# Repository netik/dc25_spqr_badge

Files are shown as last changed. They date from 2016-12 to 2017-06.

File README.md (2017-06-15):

# DEF CON 25 - The Ides of DEF CON PCB

In this folder you will find the KiCad board, schematic, and 
fabrication outputs for our Unofficial DEFCON 25 badge. The board layout was designed with [KiCad](http://kicad-pcb.org/), an open source schematic capture and PCB layout program. You will probably want the latest beta code as we had many issues working with this design and the release software.

We used **KiCad version 2016-12-18 revision 3ffa37c-master** for this design.

"fabrication-final" contains our final output gerbers which, along with the xyrs BOM file can be sent to MacroFab for construction for around $180. The cost goes down as you manufacture more boards, obviously. 

[Download the firmware source](https://github.com/netik/chibios-orchard) and flash it to this board using a SWD style debugger. 

---

Aside from the PCB and BOM that is here, you will also need:

**(qty 1) Micro SD Card, at least 4GB**

* We recommend class 4 cards because we support video playback and need some performance. 
* Copy the entire contents of the [latest SD card](https://dc25spqr.com), to the root directory of the SD Card. Name the SD card "SPQR_DC25" to be compatible with the existing update scripts if you'd like.

**(qty 1) ER-TFTM-028-4 (v4.0) 320x240 TFT Touch Screen**

* Go to Buydisplay.com: http://www.buydisplay.com/default/2-8-inch-tft-touch-shield-for-arduino-w-capacitive-touch-screen-module
* Under "Interface" select Pin Header Connection 4-Wire SPI + US$0.33
* Under "Power Supply (Typ.)" select VDD=3.3V
* Under "Touch Panel (Attached by default)" select: "2.8" Resistive Touch Panel with Controller
* Leave "Font Chip" selection empty.

**(qty 1) PKCELL 3.7v 1200mAh 3.7v LiPo with JST connector**

* Go to Adafruit, buy this: https://www.adafruit.com/product/258 ($10 or so)
* If you are creating these in bulk, go directly to PKCELL and buy them from Shenzen. They are $1.25 or so from China.
* If you use another battery, be sure and verify polarity of the JST connector!

**(qty 2 or qty 4 if you are paranoid) Standoffs and screws to hold up the screen**

* Wurth 970110151 with M2.5 x 0.45 screws
* This is Mouser part 855-R25-1001102 R25-1001102 for the M2.5 x 11mm HEX Standoff
* Screws can be had from Digkey as part 36-29300-ND MACHINE SCREW PAN SLOTTED M2.5
* The spacing is tricky and we had to work to get the screen to sit squarely on the board, substituting other standoffs will probably not work here.

**Misc**

* A small piece of double-sided tape to hold the battery to the back of the PCB. We used velcro dots, but double sided tape feels better and holds the battery closer to the board.
* A Lanyard -- we Like the "Lobster claw" type, a double-ended lanyard with two clips so you can wear the badge up and down or left-right depending on how you'd like.

--

@netik

05/04/2017

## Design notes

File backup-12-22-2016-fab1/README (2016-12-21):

These are the KiCad board, schematic, and fabrication outputs for our
Unofficial DEFCON 25 badge.

Stuff in the fabrication folder was set to MacroFab for prototype v1
on 12/20/2016. At today's prices, a board costs about $216 to make, or
$500 for two.

The firmware is available in my checkout of the chibios-orchard repo.

It's not even remotely near done yet, but I'm storing it here to keep
track of things.

--
@netik
12/20/2016

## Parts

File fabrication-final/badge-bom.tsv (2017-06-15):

# Generated by MacroFab for PCB 4dj0a6, version 10.
# DESIGNATOR | X_LOC | Y_LOC | ROTATION | SIDE | TYPE | X_SIZE | Y_SIZE | VALUE | FOOTPRINT | POPULATE | MPN | MPN1 | MPN2 | MPN3
 | 2381.84 | 2081.92 | 180 | 2 | 2 | 0 | 0 | logos:phobos_19mm_x_5.5mm 0 " 2381.84 2081.92 180 2 2 0 0 | logos:hw_200dpi | 0
 | 2381.84 | 2081.92 | 180 | 2 | 2 | 0 | 0 | logos:grimm_600dpi 0 " 2381.84 2081.92 180 2 2 0 0 | logos:redteam_31_40 | 0
 | 2381.84 | 2081.92 | 180 | 2 | 2 | 0 | 0 | logos:laurel_right 0 " 2381.84 2081.92 180 2 2 0 0 | logos:laurel | 0
A1 | 663.338 | 2281.92 | 180 | 1 | 1 | 421.26 | 188.976 | 7488910092_ANTENNA | jna-parts:Antenna_Wurth_7488910092 | 1 | 7488910092 |  |  |  | 7488910092
BT1 | 1764.72 | 2289.79 | 270 | 2 | 1 | 330.709 | 354.331 | Battery 3.7v 1000mAh | Connectors_JST:JST_PH_S2B-PH-SM4-TB_02x2.00mm_Angled | 1 | 1769 |  |  |  | 1769
C1 | 1844.44 | 2856.72 | 90 | 1 | 1 | 157.48 | 49.2126 | 0.1uF | Capacitors_SMD:C_0805_HandSoldering | 1
C10 | 2612.16 | 189.4 | 90 | 1 | 1 | 157.48 | 49.2126 | 0.1uF | Capacitors_SMD:C_0805_HandSoldering | 1
C11 | 2214.52 | 187.431 | 90 | 1 | 1 | 157.48 | 49.2126 | 0.1uF | Capacitors_SMD:C_0805_HandSoldering | 1
C12 | 1844.44 | 199.242 | 90 | 1 | 1 | 157.48 | 49.2126 | 0.1uF | Capacitors_SMD:C_0805_HandSoldering | 1
C13 | 1952.71 | 1262.23 | 0 | 1 | 1 | 157.48 | 49.2126 | 1uF | Capacitors_SMD:C_0805_HandSoldering | 1
C14 | 1677.12 | 1842.94 | 180 | 1 | 1 | 157.48 | 62.9921 | 10uF | Capacitors_SMD:C_1206 | 1
C15 | 1686.96 | 1409.87 | 0 | 1 | 1 | 157.48 | 62.9921 | 10uF | Capacitors_SMD:C_1206 | 1
C16 | 3320.82 | 2335.07 | 0 | 1 | 1 | 157.48 | 49.2126 | 220pF | Capacitors_SMD:C_0805_HandSoldering | 1 | C0805C221K5GACTU |  |  |  | C0805C221K5GACTU
C17 | 2848.38 | 2029.95 | 90 | 1 | 1 | 157.48 | 49.2126 | 11pF | Capacitors_SMD:C_0805_HandSoldering | 1 | C0805C110J5GACTU |  |  |  | C0805C110J5GACTU
C18 | 3324.75 | 2451.21 | 0 | 1 | 1 | 122.047 | 29.5276 | 0.01uF | Capacitors_SMD_C_0603_HandSoldering | 1 | MF-CAP-0603-0.01uF |  |  |  | MF-CAP-0603-0.01uF
C19 | 2730.27 | 2285.86 | 270 | 1 | 1 | 122.047 | 29.5276 | 2pF | Capacitors_SMD:C_0603_HandSoldering | 1 | C1608C0G1H020C080AA |  |  |  | C1608C0G1H020C080AA
C2 | 2218.46 | 2856.72 | 90 | 1 | 1 | 157.48 | 49.2126 | 0.1uF | Capacitors_SMD:C_0805_HandSoldering | 1
C20 | 3675.15 | 2335.07 | 0 | 1 | 1 | 157.48 | 49.2126 | 0.1uF | Capacitors_SMD:C_0805_HandSoldering | 1
C21 | 3675.15 | 2453.18 | 0 | 1 | 1 | 157.48 | 49.2126 | 0.1uF | Capacitors_SMD:C_0805_HandSoldering | 1
C22 | 2218.46 | 2128.38 | 0 | 1 | 1 | 157.48 | 49.2126 | 0.1uF | Capacitors_SMD:C_0805_HandSoldering | 1
C23 | 2592.47 | 2443.34 | 0 | 1 | 1 | 122.047 | 29.5276 | 6.8pF | Capacitors_SMD_C_0603_HandSoldering | 1 | 06035A6R8CAT2A |  |  |  | 06035A6R8CAT2A
C24 | 2415.31 | 2285.86 | 270 | 1 | 1 | 122.047 | 29.5276 | 7.5pF | 0603 | 1 | 251R14S7R5CV4T |  |  |  | 251R14S7R5CV4T
C25 | 2074.36 | 2381.92 | 270 | 1 | 1 | 157.48 | 49.2126 | 5.6pF | Capacitors_SMD:C_0805_HandSoldering | 1 | CL21C5R6CBANNNC |  |  |  | CL21C5R6CBANNNC
C26 | 1883.81 | 2423.65 | 0 | 1 | 1 | 157.48 | 49.2126 | 100pF | Capacitors_SMD:C_0805_HandSoldering | 1 | 08055A101KAT2A |  |  |  | 08055A101KAT2A
C27 | 997.983 | 1990.58 | 270 | 1 | 1 | 157.48 | 49.2126 | 1.2pF | Capacitors_SMD:C_0805_HandSoldering | 1 | CL21C1R2BBANNNC |  |  |  | CL21C1R2BBANNNC
C28 | 466.487 | 2010.27 | 270 | 1 | 1 | 157.48 | 49.2126 | 3.3pF | Capacitors_SMD:C_0805_HandSoldering | 1 | 08055A3R3CAT2A |  |  |  | 08055A3R3CAT2A
C29 | 5171.21 | 2502.39 | 180 | 1 | 1 | 157.48 | 49.2126 | 1uF | Capacitors_SMD:C_0805_HandSoldering | 1
C3 | 2612.16 | 2856.72 | 90 | 1 | 1 | 157.48 | 49.2126 | 0.1uF | Capacitors_SMD:C_0805_HandSoldering | 1
C30 | 4029.48 | 1144.12 | 0 | 1 | 1 | 157.48 | 49.2126 | 0.1uF | Capacitors_SMD:C_0805_HandSoldering | 1
C31 | 3694.83 | 1400.03 | 0 | 1 | 1 | 157.48 | 49.2126 | 10uF | Capacitors_SMD:C_0805_HandSoldering | 1 | CL21A106KQCLRNC |  |  |  | CL21A106KQCLRNC
C32 | 4226.33 | 750.423 | 90 | 1 | 1 | 157.48 | 49.2126 | 0.1uF | Capacitors_SMD:C_0805_HandSoldering | 1
C33 | 3242.08 | 2029.95 | 90 | 1 | 1 | 157.48 | 49.2126 | 11pF | Capacitors_SMD:C_0805_HandSoldering | 1 | C0805C110J5GACTU |  |  |  | C0805C110J5GACTU
C34 | 2641.29 | 1671.29 | 90 | 1 | 1 | 157.48 | 49.2126 | 0.1uF | Capacitors_SMD:C_0805_HandSoldering | 1
C35 | 3372.98 | 1666.76 | 270 | 1 | 1 | 157.48 | 49.2126 | 0.1uF | Capacitors_SMD:C_0805_HandSoldering | 1
C36 | 2777.9 | 1833.1 | 180 | 1 | 1 | 157.48 | 49.2126 | 0.1uF | Capacitors_SMD:C_0805_HandSoldering | 1
C4 | 3005.86 | 2856.72 | 90 | 1 | 1 | 157.48 | 49.2126 | 0.1uF | Capacitors_SMD:C_0805_HandSoldering | 1
C42 | 3562.55 | 1975.23 | 270 | 1 | 1 | 157.48 | 49.2126 | 10uF | Capacitors_SMD:C_0805_HandSoldering | 1 | CL21A106KQCLRNC |  |  |  | CL21A106KQCLRNC
C43 | 3682.63 | 1971.68 | 270 | 1 | 1 | 157.48 | 49.2126 | Capacitors_SMD:C_0805_HandSoldering | 1 | 1 | CL21A106KQCLRNC |  |  | CL21A106KQCLRNC | CL21A106KQCLRNC
C44 | 4025.54 | 2455.15 | 0 | 1 | 1 | 122.047 | 29.5276 | 0.01uF | Capacitors_SMD_C_0603_HandSoldering | 1 | MF-CAP-0603-0.01uF |  |  |  | MF-CAP-0603-0.01uF
C45 | 4014.52 | 2135.86 | 270 | 1 | 1 | 98.4 | 200.5 | 10uF | MF_Passives:MF_Passives-CP4MM | 1 | MF-CAP-4MM-10uF |  |  |  | MF-CAP-4MM-10uF
C46 | 4675.15 | 2608.69 | 180 | 1 | 1 | 98.4 | 200.5 | 10uF | MF_Passives:MF_Passives-CP4MM | 1 | MF-CAP-4MM-10uF |  |  |  | MF-CAP-4MM-10uF
C47 | 3844.05 | 1657.9 | 270 | 1 | 1 | 157.48 | 49.2126 | .047uF | Capacitors_SMD:C_0805_HandSoldering | 1 | 08053C473JAT2A |  |  |  | 08053C473JAT2A
C48 | 4014.52 | 1721.68 | 180 | 1 | 1 | 157.48 | 49.2126 | 10uF | Capacitors_SMD:C_0805_HandSoldering | 1 | CL21A106KQCLRNC |  |  |  | CL21A106KQCLRNC
C49 | 4899.56 | 1880.34 | 180 | 1 | 1 | 125.9 | 275.3 | 100uF | MF_Passives:MF_Passives-CP6.3MM | 1 | MF-CAP-6.3MM-100uF |  |  |  | MF-CAP-6.3MM-100uF
C5 | 3399.56 | 2856.72 | 90 | 1 | 1 | 157.48 | 49.2126 | 0.1uF | Capacitors_SMD:C_0805_HandSoldering | 1
C6 | 3793.26 | 2856.72 | 90 | 1 | 1 | 157.48 | 49.2126 | 0.1uF | Capacitors_SMD:C_0805_HandSoldering | 1
C7 | 3793.26 | 199.242 | 90 | 1 | 1 | 157.48 | 49.2126 | 0.1uF | Capacitors_SMD:C_0805_HandSoldering | 1
C8 | 3399.56 | 199.242 | 90 | 1 | 1 | 157.48 | 49.2126 | 0.1uF | Capacitors_SMD:C_0805_HandSoldering | 1
C9 | 3005.86 | 199.242 | 90 | 1 | 1 | 157.48 | 49.2126 | 0.1uF | Capacitors_SMD:C_0805_HandSoldering | 1
D1 | 4521.61 | 2423.65 | 0 | 1 | 1 | 129.8 | 47.2 | RED PWROK | LEDs:LED_0805 | 1 | MF-LED-0805-RED |  |  |  | MF-LED-0805-RED
D2 | 4521.61 | 2226.8 | 0 | 1 | 1 | 129.8 | 47.2 | GREEN SDIO | LEDs:LED_0805 | 1 | MF-LED-0805-GREEN |  |  |  | MF-LED-0805-GREEN
D3 | 4521.61 | 2029.95 | 0 | 1 | 1 | 129.8 | 47.2 | RED UTX | LEDs:LED_0805 | 1 | MF-LED-0805-RED |  |  |  | MF-LED-0805-RED
D4 | 4521.61 | 1833.1 | 0 | 1 | 1 | 129.8 | 47.2 | GREEN URX | LEDs:LED_0805 | 1 | MF-LED-0805-GREEN |  |  |  | MF-LED-0805-GREEN
D5 | 4521.61 | 1636.25 | 0 | 1 | 1 | 129.8 | 47.2 | RED (CHARGING) | LEDs:LED_0805 | 1 | MF-LED-0805-RED |  |  |  | MF-LED-0805-RED
D6 | 4521.61 | 1439.4 | 0 | 1 | 1 | 129.8 | 47.2 | GRN (DONE) | LEDs:LED_0805 | 1 | MF-LED-0805-GREEN |  |  |  | MF-LED-0805-GREEN
D7 | 4521.61 | 1242.55 | 0 | 1 | 1 | 129.8 | 47.2 | RED RFTX | LEDs:LED_0805 | 1 | MF-LED-0805-RED |  |  |  | MF-LED-0805-RED
D8 | 4521.61 | 1045.7 | 0 | 1 | 1 | 129.8 | 47.2 | GRN RFRX | LEDs:LED_0805 | 1 | MF-LED-0805-GREEN |  |  |  | MF-LED-0805-GREEN
H1 | 1679.09 | 2659.87 | 0 | 1 | 2 | 125.984 | 125.984 | CONN_01X01 | Mounting_Holes_MountingHole_3_2mm_M3_DIN965 | 0
H2 | 4297.2 | 2663.81 | 0 | 1 | 2 | 125.984 | 125.984 | CONN_01X01 | Mounting_Holes_MountingHole_3_2mm_M3_DIN965 | 0
H3 | 1679.09 | 459.085 | 0 | 1 | 2 | 125.984 | 125.984 | CONN_01X01 | Mounting_Holes_MountingHole_3_2mm_M3_DIN965 | 0
H4 | 4297.2 | 459.085 | 0 | 1 | 2 | 125.984 | 125.984 | CONN_01X01 | Mounting_Holes_MountingHole_3_2mm_M3_DIN965 | 0
H5 | 1253.89 | 2856.72 | 0 | 1 | 2 | 125.984 | 125.984 | CONN_01X01 | Mounting_Holes_MountingHole_3_2mm_M3_DIN965 | 0
H6 | 4757.83 | 2856.72 | 0 | 1 | 2 | 125.984 | 125.984 | CONN_01X01 | Mounting_Holes_MountingHole_3_2mm_M3_DIN965 | 0
H7 | 144.046 | 1504.2 | 0 | 1 | 2 | 125.984 | 125.984 | CONN_01X01 | Mounting_Holes_MountingHole_3_2mm_M3_DIN965 | 0
J2 | 2560.58 | 671.093 | 90 | 1 | 2 | 91.3386 | 241.339 | JTAG | Pin_Headers:Pin_Header_Straight_2x05_Pitch1.27mm | 1 | M50-3500542 |  |  |  | M50-3500542
L1 | 2897.59 | 2433.49 | 90 | 1 | 1 | 78.8 | 47.2 | 4.7nH | Inductors_NEOSID:Neosid_Inductor_SM0603CG | 1 | LQG18HN4N7S00D |  |  |  | LQG18HN4N7S00D
L2 | 3074.75 | 2433.49 | 90 | 1 | 1 | 78.8 | 47.2 | 33nH | Inductors_NEOSID:Neosid_Inductor_SM0603CG | 1 | CI160808-33NJ |  |  |  | CI160808-33NJ
L3 | 2395.62 | 2443.34 | 180 | 1 | 1 | 78.8 | 47.2 | 0.0068 uH | Inductors_NEOSID:Neosid_Inductor_SM0603CG | 1 | CI160808-6N8J |  |  |  | CI160808-6N8J
L4 | 2218.46 | 2443.34 | 180 | 1 | 1 | 78.8 | 47.2 | 0.0068 uH | Inductors_NEOSID:Neosid_Inductor_SM0603CG | 1 | CI160808-6N8J |  |  |  | CI160808-6N8J
L5 | 761.763 | 2029.95 | 90 | 1 | 1 | 78.8 | 47.2 | 15nH | Inductors_NEOSID_Neosid_Inductor_SM0603CG | 1 | HK160815NJ-T |  |  |  | HK160815NJ-T
P2 | 1298.77 | 1557.19 | 90 | 1 | 2 | 1968 | 168 | CONN_02X20 | jna-parts:IDC_HEADER_FEMALE | 1 | SFH11-PBPC-D20-ST-BK |  |  |  | SFH11-PBPC-D20-ST-BK
P3 | 3070.82 | 671.683 | 270 | 1 | 2 | 80 | 568 | FTDI BACKUP | Pin_Headers_Pin_Header_Straight_1x06 | 0
P4 | 4505.86 | 122.751 | 180 | 2 | 1 | 306.9 | 174.15 | USB_MICRO_RIGHT | MF_Connectors:MF_Connectors-MICROUSB-RIGHT | 1 | 105017-0001 |  |  |  | MF-CON-MICROUSB-RIGHT
P5 | 4684.6 | 478.77 | 90 | 1 | 2 | 80 | 268 | LED OUT (DNP) | Pin_Headers_Pin_Header_Straight_1x03 | 0
R10 | 4344.44 | 1045.7 | 0 | 1 | 1 | 102.362 | 51.1811 | 220 | Resistors_SMD:R_0805 | 1
R11 | 4344.44 | 1242.55 | 0 | 1 | 1 | 102.362 | 51.1811 | 220 | Resistors_SMD:R_0805 | 1
R12 | 4344.44 | 2423.65 | 0 | 1 | 1 | 102.362 | 51.1811 | 220 | Resistors_SMD:R_0805 | 1
R13 | 4344.44 | 2029.95 | 0 | 1 | 1 | 102.362 | 51.1811 | 1k | Resistors_SMD:R_0805 | 1
R14 | 4344.44 | 1833.1 | 180 | 1 | 1 | 102.362 | 51.1811 | 1k | Resistors_SMD:R_0805 | 1
R15 | 4344.44 | 1439.4 | 0 | 1 | 1 | 102.362 | 51.1811 | 1k | Resistors_SMD:R_0805 | 1
R16 | 4344.44 | 1636.25 | 0 | 1 | 1 | 102.362 | 51.1811 | 1k | Resistors_SMD:R_0805 | 1
R19 | 3562.55 | 1795.7 | 270 | 1 | 1 | 102.362 | 51.1811 | 1k | Resistors_SMD:R_0805 | 1
R2 | 1982.24 | 1833.1 | 180 | 1 | 1 | 102.362 | 51.1811 | 100 | Resistors_SMD:R_0805 | 1
R20 | 3684.6 | 1796.49 | 270 | 1 | 1 | 102.362 | 51.1811 | 1k | Resistors_SMD:R_0805 | 1
R21 | 3994.05 | 2337.04 | 0 | 1 | 1 | 102.362 | 51.1811 | 100k | Resistors_SMD:R_0805 | 1
R22 | 3680.66 | 2148.85 | 90 | 1 | 1 | 102.362 | 51.1811 | 1k | Resistors_SMD:R_0805 | 1 | MF-RES-0805-1K |  |  |  | MF-RES-0805-1K
R23 | 4029.48 | 1533.89 | 180 | 1 | 1 | 102.362 | 51.1811 | 10k | Resistors_SMD:R_0805 | 1
R3 | 4029.48 | 1340.97 | 180 | 1 | 1 | 102.362 | 51.1811 | 10k | Resistors_SMD:R_0805 | 1
R5 | 1972.39 | 1459.08 | 0 | 1 | 1 | 102.362 | 51.1811 | 2k | Resistors_SMD:R_0805 | 1
R6 | 1978.3 | 1604.75 | 0 | 1 | 1 | 102.362 | 51.1811 | 10k | Resistors_SMD:R_0805 | 1
R8 | 4954.68 | 947.274 | 0 | 1 | 1 | 102.362 | 51.1811 | 10K | Resistors_SMD:R_0805 | 1
R9 | 4344.44 | 2226.8 | 0 | 1 | 1 | 102.362 | 51.1811 | 220 | Resistors_SMD:R_0805 | 1
SP2 | 5434.99 | 1990.58 | 0 | 1 | 2 | 359.213 | 60 | MODEL TBD | jna-parts:SPEAKER_AST_01708MR_R | 1 | AST-01708MR-R |  |  |  | AST-01708MR-R
SW1 | 1677.12 | 179.557 | 90 | 1 | 1 | 188.7 | 125.9 | RESET | MF_Switches:MF_Switches-TACT4.2MM | 1 | MF-SW-TACT-4.2MM |  |  |  | MF-SW-TACT-4.2MM
SW2 | 1362.16 | 147.077 | 180 | 2 | 1 | 326.772 | 157.48 | POWERON | Buttons_Switches_SMD_SW_SPDT_PCM12 | 1 | PCM12SMTR |  |  |  | PCM12SMTR
SW3 | 2127.9 | 1604.75 | 90 | 1 | 2 | 229.291 | 60 | TM1000 | jna-parts:TM1000 | 1 | TM1000Q |  |  |  | TM1000Q
SW4 | 636.645 | 1702.71 | 0 | 1 | 1 | 188.7 | 125.9 | UP hide | MF_Switches:MF_Switches-TACT4.2MM | 1 | MF-SW-TACT-4.2MM |  |  |  | MF-SW-TACT-4.2MM
SW5 | 636.645 | 1322.71 | 0 | 1 | 1 | 188.7 | 125.9 | DN hide | MF_Switches:MF_Switches-TACT4.2MM | 1 | MF-SW-TACT-4.2MM |  |  |  | MF-SW-TACT-4.2MM
SW6 | 416.645 | 1502.71 | 0 | 1 | 1 | 188.7 | 125.9 | LEFT hide | MF_Switches:MF_Switches-TACT4.2MM | 1 | MF-SW-TACT-4.2MM |  |  |  | MF-SW-TACT-4.2MM
SW7 | 846.645 | 1502.71 | 0 | 1 | 1 | 188.7 | 125.9 | RIGHT hide | MF_Switches:MF_Switches-TACT4.2MM | 1 | MF-SW-TACT-4.2MM |  |  |  | MF-SW-TACT-4.2MM
SW8 | 5407.43 | 1498.45 | 0 | 1 | 1 | 188.7 | 125.9 | ENTER | MF_Switches:MF_Switches-TACT4.2MM | 1 | MF-SW-TACT-4.2MM |  |  |  | MF-SW-TACT-4.2MM
TP1 | 5044.05 | 2244.2 | 0 | 1 | 2 | 59.0551 | 59.0551 | PTA4 | Measurement_Points_Measurement_Point_Round_TH_Small | 0
TP10 | 2080.66 | 675.62 | 0 | 1 | 2 | 59.0551 | 59.0551 | GND | Measurement_Points_Measurement_Point_Round_TH_Small | 0
TP17 | 1954.68 | 770.108 | 0 | 1 | 2 | 59.0551 | 59.0551 | SPI_CH1_SCLK | Measurement_Points_Measurement_Point_Round_TH_Small | 0
TP18 | 3035.38 | 2177.59 | 0 | 1 | 2 | 59.0551 | 59.0551 | CLOCKOUT | Measurement_Points_Measurement_Point_Round_TH_Small | 0
TP19 | 2080.66 | 770.108 | 0 | 1 | 2 | 59.0551 | 59.0551 | SPI_CH1_MOSI | Measurement_Points_Measurement_Point_Round_TH_Small | 0
TP2 | 4964.05 | 2244.2 | 0 | 1 | 2 | 59.0551 | 59.0551 | GND | Measurement_Points_Measurement_Point_Round_TH_Small | 0
TP20 | 2198.77 | 770.108 | 0 | 1 | 2 | 59.0551 | 59.0551 | SPI_CH1_MISO | Measurement_Points_Measurement_Point_Round_TH_Small | 0
TP3 | 2198.77 | 675.62 | 0 | 1 | 2 | 59.0551 | 59.0551 | VCC | Measurement_Points_Measurement_Point_Round_TH_Small | 0
TP4 | 1954.68 | 675.62 | 0 | 1 | 2 | 59.0551 | 59.0551 | VBAT | Measurement_Points_Measurement_Point_Round_TH_Small | 0
TP5 | 1844.44 | 770.108 | 0 | 1 | 2 | 59.0551 | 59.0551 | GND | Measurement_Points_Measurement_Point_Round_TH_Small | 0
U1 | 2021.61 | 2856.72 | 90 | 1 | 1 | 228.2 | 188.8 | WS2812B | MF_LEDs:MF_LEDs-WS2812B | 1 | 1655 |  |  |  | 1655
U10 | 2809.01 | 195.305 | 90 | 1 | 1 | 228.2 | 188.8 | WS2812B | MF_LEDs:MF_LEDs-WS2812B | 1 | 1655 |  |  |  | 1655
U11 | 2415.31 | 189.4 | 90 | 1 | 1 | 228.2 | 188.8 | WS2812B | MF_LEDs:MF_LEDs-WS2812B | 1 | 1655 |  |  |  | 1655
U12 | 2021.61 | 189.4 | 90 | 1 | 1 | 228.2 | 188.8 | WS2812B | MF_LEDs:MF_LEDs-WS2812B | 1 | 1655 |  |  |  | 1655
U13 | 2995.93 | 1501.61 | 0 | 1 | 1 | 333.339 | 333.339 | MKW01Z128 | jna-parts:mkw01z128 | 1 | MKW01Z128CHN |  |  | MKW01Z128CHN | MKW01Z128CHN
U14 | 3931.05 | 809.478 | 0 | 1 | 1 | 352.362 | 350.394 | FT232RL SSOP | Housings_SSOP:SSOP-28_5.3x10.2mm_Pitch0.65mm | 1 | FT232RL-REEL |  |  |  | FT232RL-REEL
U15 | 1686.96 | 1203.18 | 90 | 1 | 1 | 128.346 | 100.394 | MF-REG-SOT235-3.3V-300mA | TO_SOT_Packages_SMD:SOT-23-5 | 1
U16 | 1677.12 | 1636.25 | 90 | 1 | 1 | 128.346 | 100.394 | MCP73831T-2ACI/OT | TO_SOT_Packages_SMD:SOT-23-5 | 1
U18 | 4020.42 | 1889.79 | 270 | 1 | 1 | 170 | 295 | LM386 | SMD_Packages:SOIC-8-N | 1 | LM386MX-1/NOPB |  |  |  | LM386MX-1/NOPB
U2 | 2415.31 | 2856.72 | 90 | 1 | 1 | 228.2 | 188.8 | WS2812B | MF_LEDs:MF_LEDs-WS2812B | 1 | 1655 |  |  |  | 1655
U3 | 2809.01 | 2856.72 | 90 | 1 | 1 | 228.2 | 188.8 | WS2812B | MF_LEDs:MF_LEDs-WS2812B | 1 | 1655 |  |  |  | 1655
U4 | 3202.71 | 2856.72 | 90 | 1 | 1 | 228.2 | 188.8 | WS2812B | MF_LEDs:MF_LEDs-WS2812B | 1 | 1655 |  |  |  | 1655
U5 | 3596.41 | 2856.72 | 90 | 1 | 1 | 228.2 | 188.8 | WS2812B | MF_LEDs:MF_LEDs-WS2812B | 1 | 1655 |  |  |  | 1655
U6 | 3990.11 | 2856.72 | 90 | 1 | 1 | 228.2 | 188.8 | WS2812B | MF_LEDs:MF_LEDs-WS2812B | 1 | 1655 |  |  |  | 1655
U7 | 3990.11 | 199.242 | 90 | 1 | 1 | 228.2 | 188.8 | WS2812B | MF_LEDs:MF_LEDs-WS2812B | 1 | 1655 |  |  |  | 1655
U8 | 3596.41 | 199.242 | 90 | 1 | 1 | 228.2 | 188.8 | WS2812B | MF_LEDs:MF_LEDs-WS2812B | 1 | 1655 |  |  |  | 1655
U9 | 3202.71 | 199.242 | 90 | 1 | 1 | 228.2 | 188.8 | WS2812B | MF_LEDs:MF_LEDs-WS2812B | 1 | 1655 |  |  |  | 1655
Y1 | 3041.29 | 2014.2 | 0 | 1 | 1 | 141.732 | 110.236 | EXS00A-CS02368 | jna-parts:Crystal_EXS00A-CS02368 | 1 | NX3225SA-32MHZ-EXS00A-CS02368 |  |  |  | NX3225SA-32MHZ-EXS00A-CS02368

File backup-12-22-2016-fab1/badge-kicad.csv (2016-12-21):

Id | Designator | Package | Quantity | Designation | Supplier and ref
1 | P3 | Pin_Header_Straight_1x06 | 1 | FTDI BACKUP
2 | W14 | Test_Point_Keystone_5005-5009_Compact | 1 | PTC4
3 | W13 | Test_Point_Keystone_5005-5009_Compact | 1 | PTC3
4 | W12 | Test_Point_Keystone_5005-5009_Compact | 1 | PTC1
5 | W11 | Test_Point_Keystone_5005-5009_Compact | 1 | PTB1
6 | TP5 | Test_Point_Keystone_5005-5009_Compact | 1 | GND
7 | W8 | Test_Point_Keystone_5005-5009_Compact | 1 | PTD6
8 | W1 | Test_Point_Keystone_5005-5009_Compact | 1 | SPI_CH1_MOSI
9 | W2 | Test_Point_Keystone_5005-5009_Compact | 1 | SPI_CH1_MISO
10 | W3 | Test_Point_Keystone_5005-5009_Compact | 1 | SPI_CH1_SCLK
11 | W4 | Test_Point_Keystone_5005-5009_Compact | 1 | LED_DATA_OUT
12 | TP4 | Test_Point_Keystone_5005-5009_Compact | 1 | VBAT
13 | C8,C9,C10,C11,C12,C6,C1,C2,C20,C21,C7,C4,C5,C3 | C_1206_HandSoldering | 14 | 100nF
14 | C13 | C_1206_HandSoldering | 1 | 1uF
15 | C14,C15,C31 | C_1206_HandSoldering | 3 | 10uF
16 | C17 | C_1206_HandSoldering | 1 | 100uF
17 | C18,C19 | C_1206_HandSoldering | 2 | 11pF
18 | C23 | C_1206_HandSoldering | 1 | 6.8pF
19 | C24 | C_1206_HandSoldering | 1 | 100pF
20 | C25 | C_1206_HandSoldering | 1 | 7.5pF
21 | C26 | C_1206_HandSoldering | 1 | 5.6pF
22 | C27,C28 | C_1206_HandSoldering | 2 | 1.2pF
23 | C29 | C_1206_HandSoldering | 1 | 2.0pF
24 | C30,C32,C22 | C_1206_HandSoldering | 3 | 0.1uF
25 | U15 | SOT-23-5 | 1 | TPS76333
26 | U16 | SOT-23-5 | 1 | MCP73831T-2ACI/OT
27 | R3,R6 | R_1206 | 2 | 10k
28 | A1 | Antenna_Wurth_7488910092 | 1 | 7488910092_ANTENNA
29 | D5 | LED_1206 | 1 | RED (CHARGING)
30 | D6 | LED_1206 | 1 | GRN (DONE)
31 | R5 | R_1206 | 1 | 2k
32 | R15,R16,R14,R13 | R_1206 | 4 | 1k
33 | P1 | TM1000 | 1 | TM1000
34 | SP1 | TDK_PS1720PD2 | 1 | TDK PS1720P02
35 | P2 | IDC_Header_Straight_40pins | 1 | CONN_02X20
36 | P4 | USB_Mini-B | 1 | USB_OTG
37 | U14 | SSOP-28_5.3x10.2mm_Pitch0.65mm | 1 | FT232RL SSOP
38 | D2 | LED-RGB-5MM_Common_Cathode | 1 | LED_RCBG
39 | D3 | LED_1206 | 1 | RED
40 | U2,U1,U10,U9,U8,U7,U6,U5,U4,U3,U12,U11 | LED_WS2812B-PLCC4 | 12 | WS2812B
41 | U13 | 98ASA00302D | 1 | MKW01Z128
42 | SW1 | SW_SPST_B3S-1000 | 1 | SW_PUSH
43 | J2 | IDC_Header_Straight_10pins | 1 | JTAG
44 | BT1 | JST_PH_S2B-PH-SM4-TB_02x2.00mm_Angled | 1 | Battery 3.7v 1000mAh
45 | Y1 | Crystal_SMD_0603_4Pads | 1 | 32Mhz XTAL
46 | L2,L3 | Neosid_Inductor_SM1206 | 2 | 0.0068 uH
47 | L4 | Neosid_Inductor_SM1206 | 1 | 15 NH
48 | L1 | Neosid_Inductor_SM1206 | 1 | 0.0047 uH
49 | D1 | LED_1206 | 1 | POWER
50 | D4 | LED_1206 | 1 | GREEN
51 | TP1 | Test_Point_Keystone_5005-5009_Compact | 1 | PTA4
52 | R11,R12,R9,R10 | R_1206 | 4 | 220
53 | R1 | R_1206 | 1 | 1K
54 | R4 | R_1206 | 1 | 120
55 | R7,R2 | R_1206 | 2 | 100
56 | R8 | R_1206 | 1 | 10K
57 | Q1 | SOT-323 | 1 | 2N3904

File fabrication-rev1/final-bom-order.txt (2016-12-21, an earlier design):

Designators	Part Number	Count	Unit Cost
C26	08051A5R6CAT2A	2	$0.324
C23	08051A6R8CAT2A	2	$0.204
P2	1-215307-0	2	$3.096
P4	105017-0001	2	$0.876
D2	150080BS75000	2	$0.216
BT1	1769	2	$0.900
C25	251R15S7R5CV4E	2	$0.240
L4	36502A15NJTDG	2	$0.192
A1	7488910092	2	$4.440
Y1	AWSCR-32.00CW-T	2	$0.552
C29	C0805C209C5GACTU	2	$0.396
C24	CC0805JRNPO9BN101	2	$0.120
C14, C15, C31	CL21A106KQFNNNG	6	$0.120
C27, C28	CL21C1R2BBANNNC	4	$0.120
U14	FT232RL-TUBE	2	$5.400
C17	GRM21BR60G107ME15L	2	$1.416
L2, L3	IMC0805ER6N8J01	4	$0.156
L1	KL732ATTE4N7C	2	$0.768
J2	M50-3500542	2	$1.416
U16	MCP73831T-2ACI/OT	2	$0.696
C5, C6, C7, C8, C9, C10, C11, C12, C3, C20, C21, C22, C30, C32, C4, C1, C2	MF-CAP-0805-0.1uF	34	$0.011
C13	MF-CAP-0805-1uF	2	$0.060
D4, D6, D8	MF-LED-0805-GREEN	6	$0.080
D1, D3, D7, D5	MF-LED-0805-RED	8	$0.080
R2, R4, R7	MF-RES-0805-100	6	$0.050
R3, R6, R8	MF-RES-0805-10K	6	$0.050
R16, R15, R14, R13, R1	MF-RES-0805-1K	10	$0.010
R10, R12, R11, R9	MF-RES-0805-220	8	$0.050
R5	MF-RES-0805-2K	2	$0.050
U13	MKW01Z128CHN	2	$4.824
Q1	MMBT3904LT1G	2	$0.120
SP1	PS1720P02	2	$0.876
SW1	TL3301NF160QG	2	$0.468
P1	TM1000Q	2	$1.848
U15	TPS76333DBVR	2	$1.068
U9, U3, U2, U1, U10, U8, U7, U6, U5, U4, U12, U11	WS2812B	24	$0.200

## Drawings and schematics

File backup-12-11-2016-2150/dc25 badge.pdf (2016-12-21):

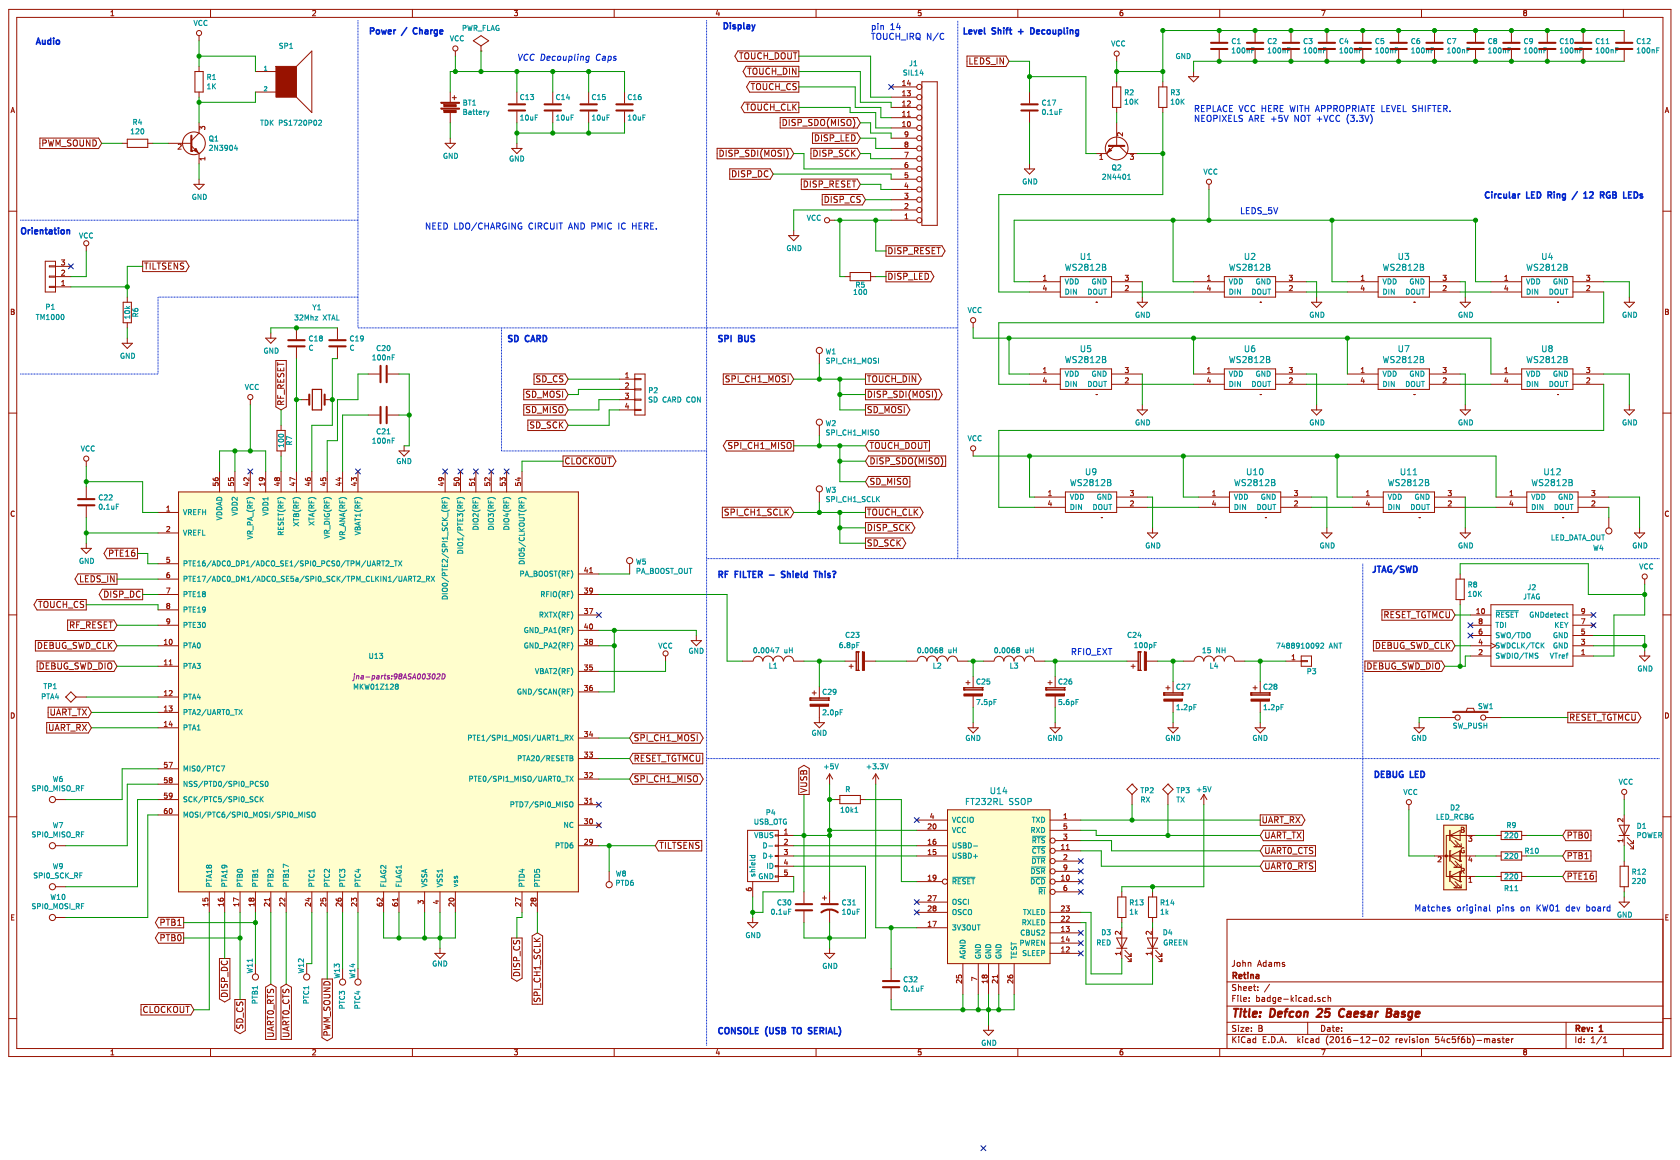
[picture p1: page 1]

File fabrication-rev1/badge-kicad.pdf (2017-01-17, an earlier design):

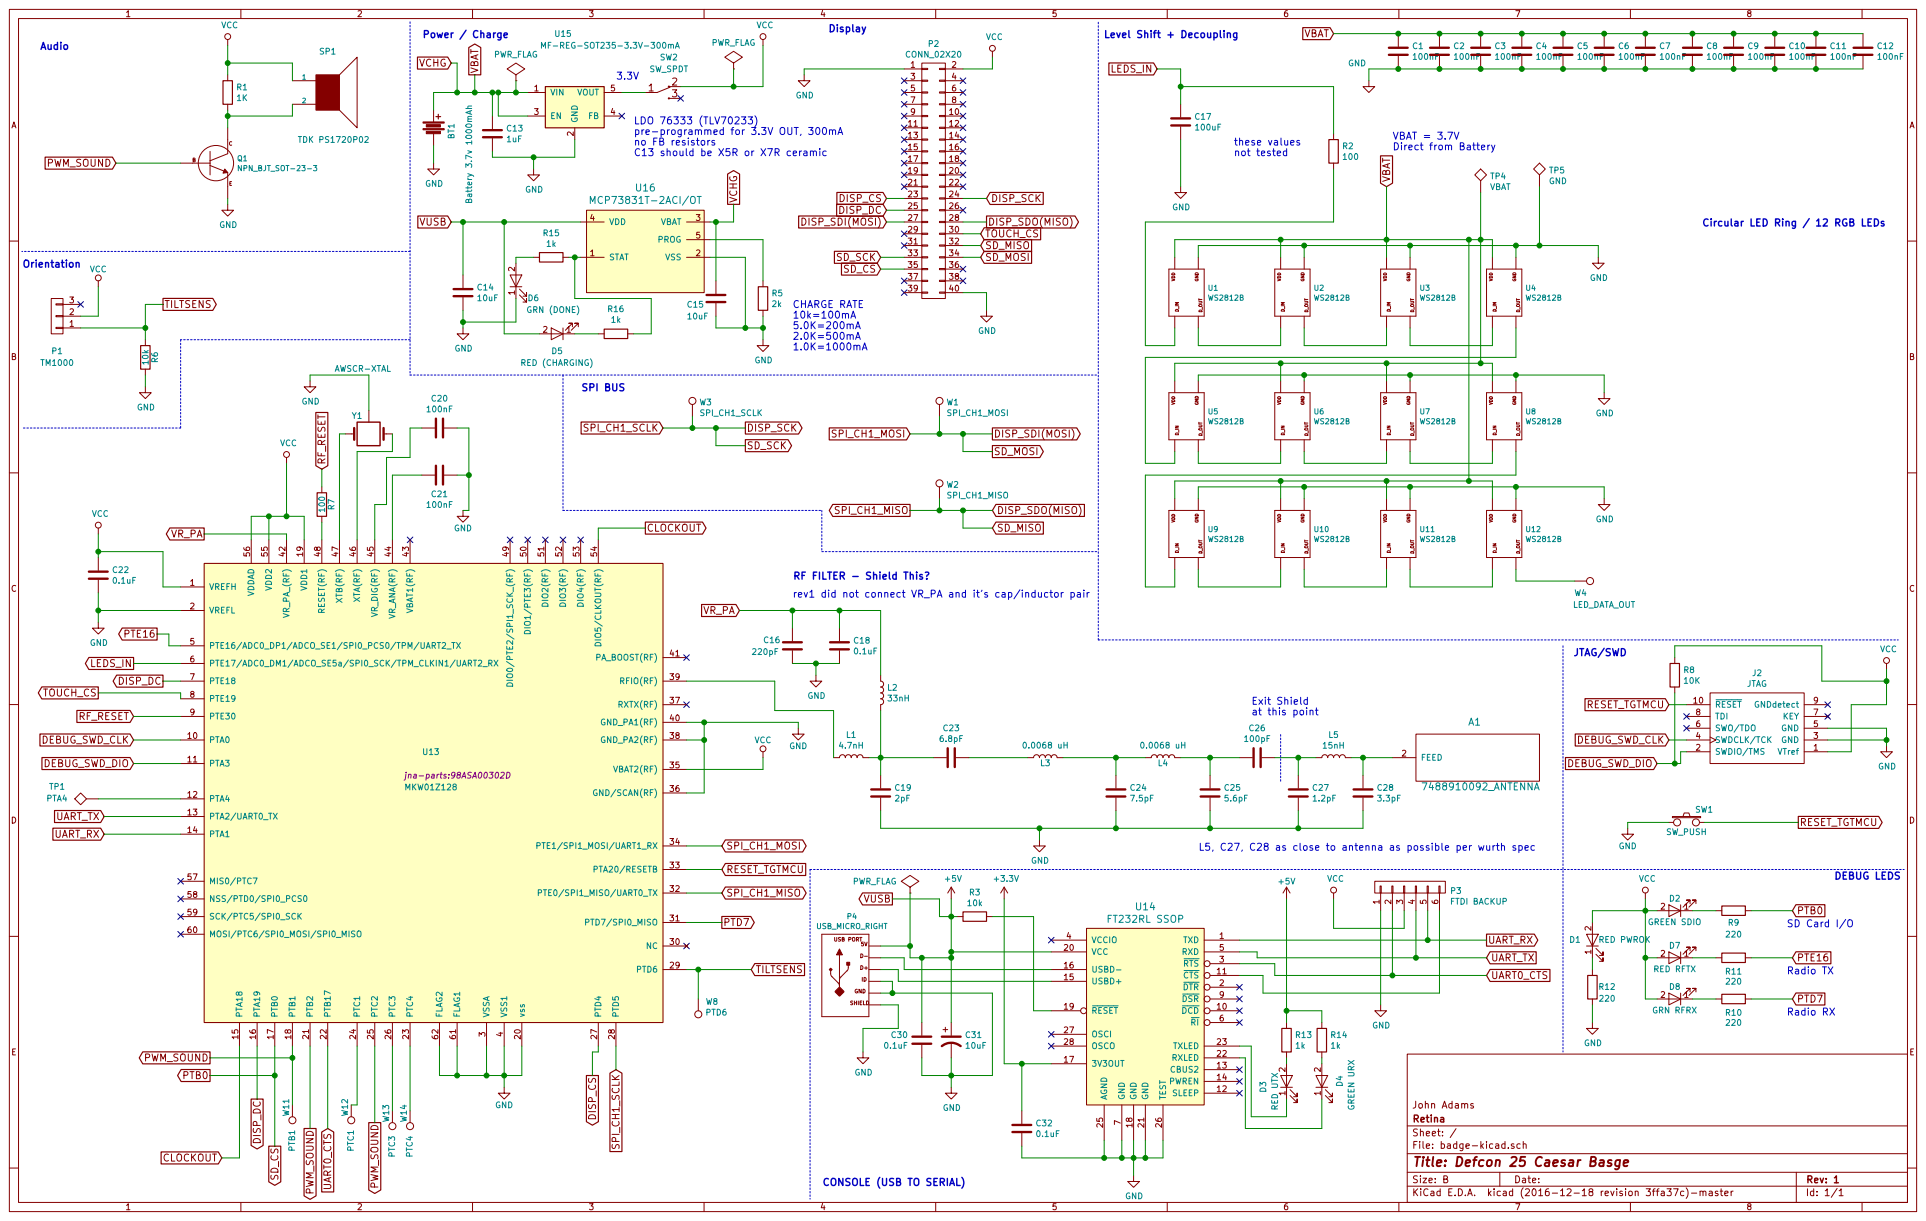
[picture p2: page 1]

2 EN 3 FB 4 VOUT 5 U15 MF-REG-SOT235-3.3V-300mA

LDO 76333 (TLV70233)
pre-programmed for 3.3V OUT, 300mA

these values not tested

4 PTE16/ADC0_DP1/ADCO_SE1/SPI0_PCS0/TPM/UART2_TX 5 PTE17/ADC0_DM1/ADCO_SE5a/SPI0_SCK/TPM_CLKIN1/UART2_RX 6 PTE18 7 PTE19 8 PTE30 9 PTA0 10 vss 20 NC 30 GND_PA1(RF) 40 DIO1/PTE3(RF) 50 MOSI/PTC6/SPI0_MOSI/SPI0_MISO 60 PTA3 11 PTB2 21 PTD7/SPI0_MISO 31 PA_BOOST(RF) 41 DIO2(RF) 51 FLAG1 61 PTA4 12 PTB17 22 PTE0/SPI1_MISO/UART0_TX 32 VR_PA_(RF) 42 DIO3(RF) 52 FLAG2 62 PTA2/UART0_TX 13 PTC4 23 PTA20/RESETB 33 VBAT1(RF) 43 DIO4(RF) 53 PTA1 14 PTC1 24 PTE1/SPI1_MOSI/UART1_RX 34 VR_ANA(RF) 44 DIO5/CLKOUT(RF) 54 PTA18 15 PTC2 25

0.0068 uH RF FILTER - Shield This? GND GND SD_CS

rev1 did not connect VR_PA and its cap/inductor pair GND

L5, C27, C28 as close to antenna as possible per wurth spec

7 DSR 9 DCD 10 VCC 20 CTS 11 GND 21 SLEEP 12 RXLED 22 CBUS2 13 TXLED 23 PWREN 14 USBD+ 15 AGND 25 USBD- 16 TEST 26

1 2 D3 RED UTX 1 2 D4 GREEN URX R14

GND CONSOLE (USB TO SERIAL) GND

File: badge-kicad.sch Sheet: / Retina

Id: 1/1 Title: Defcon 25 Caesar Basge

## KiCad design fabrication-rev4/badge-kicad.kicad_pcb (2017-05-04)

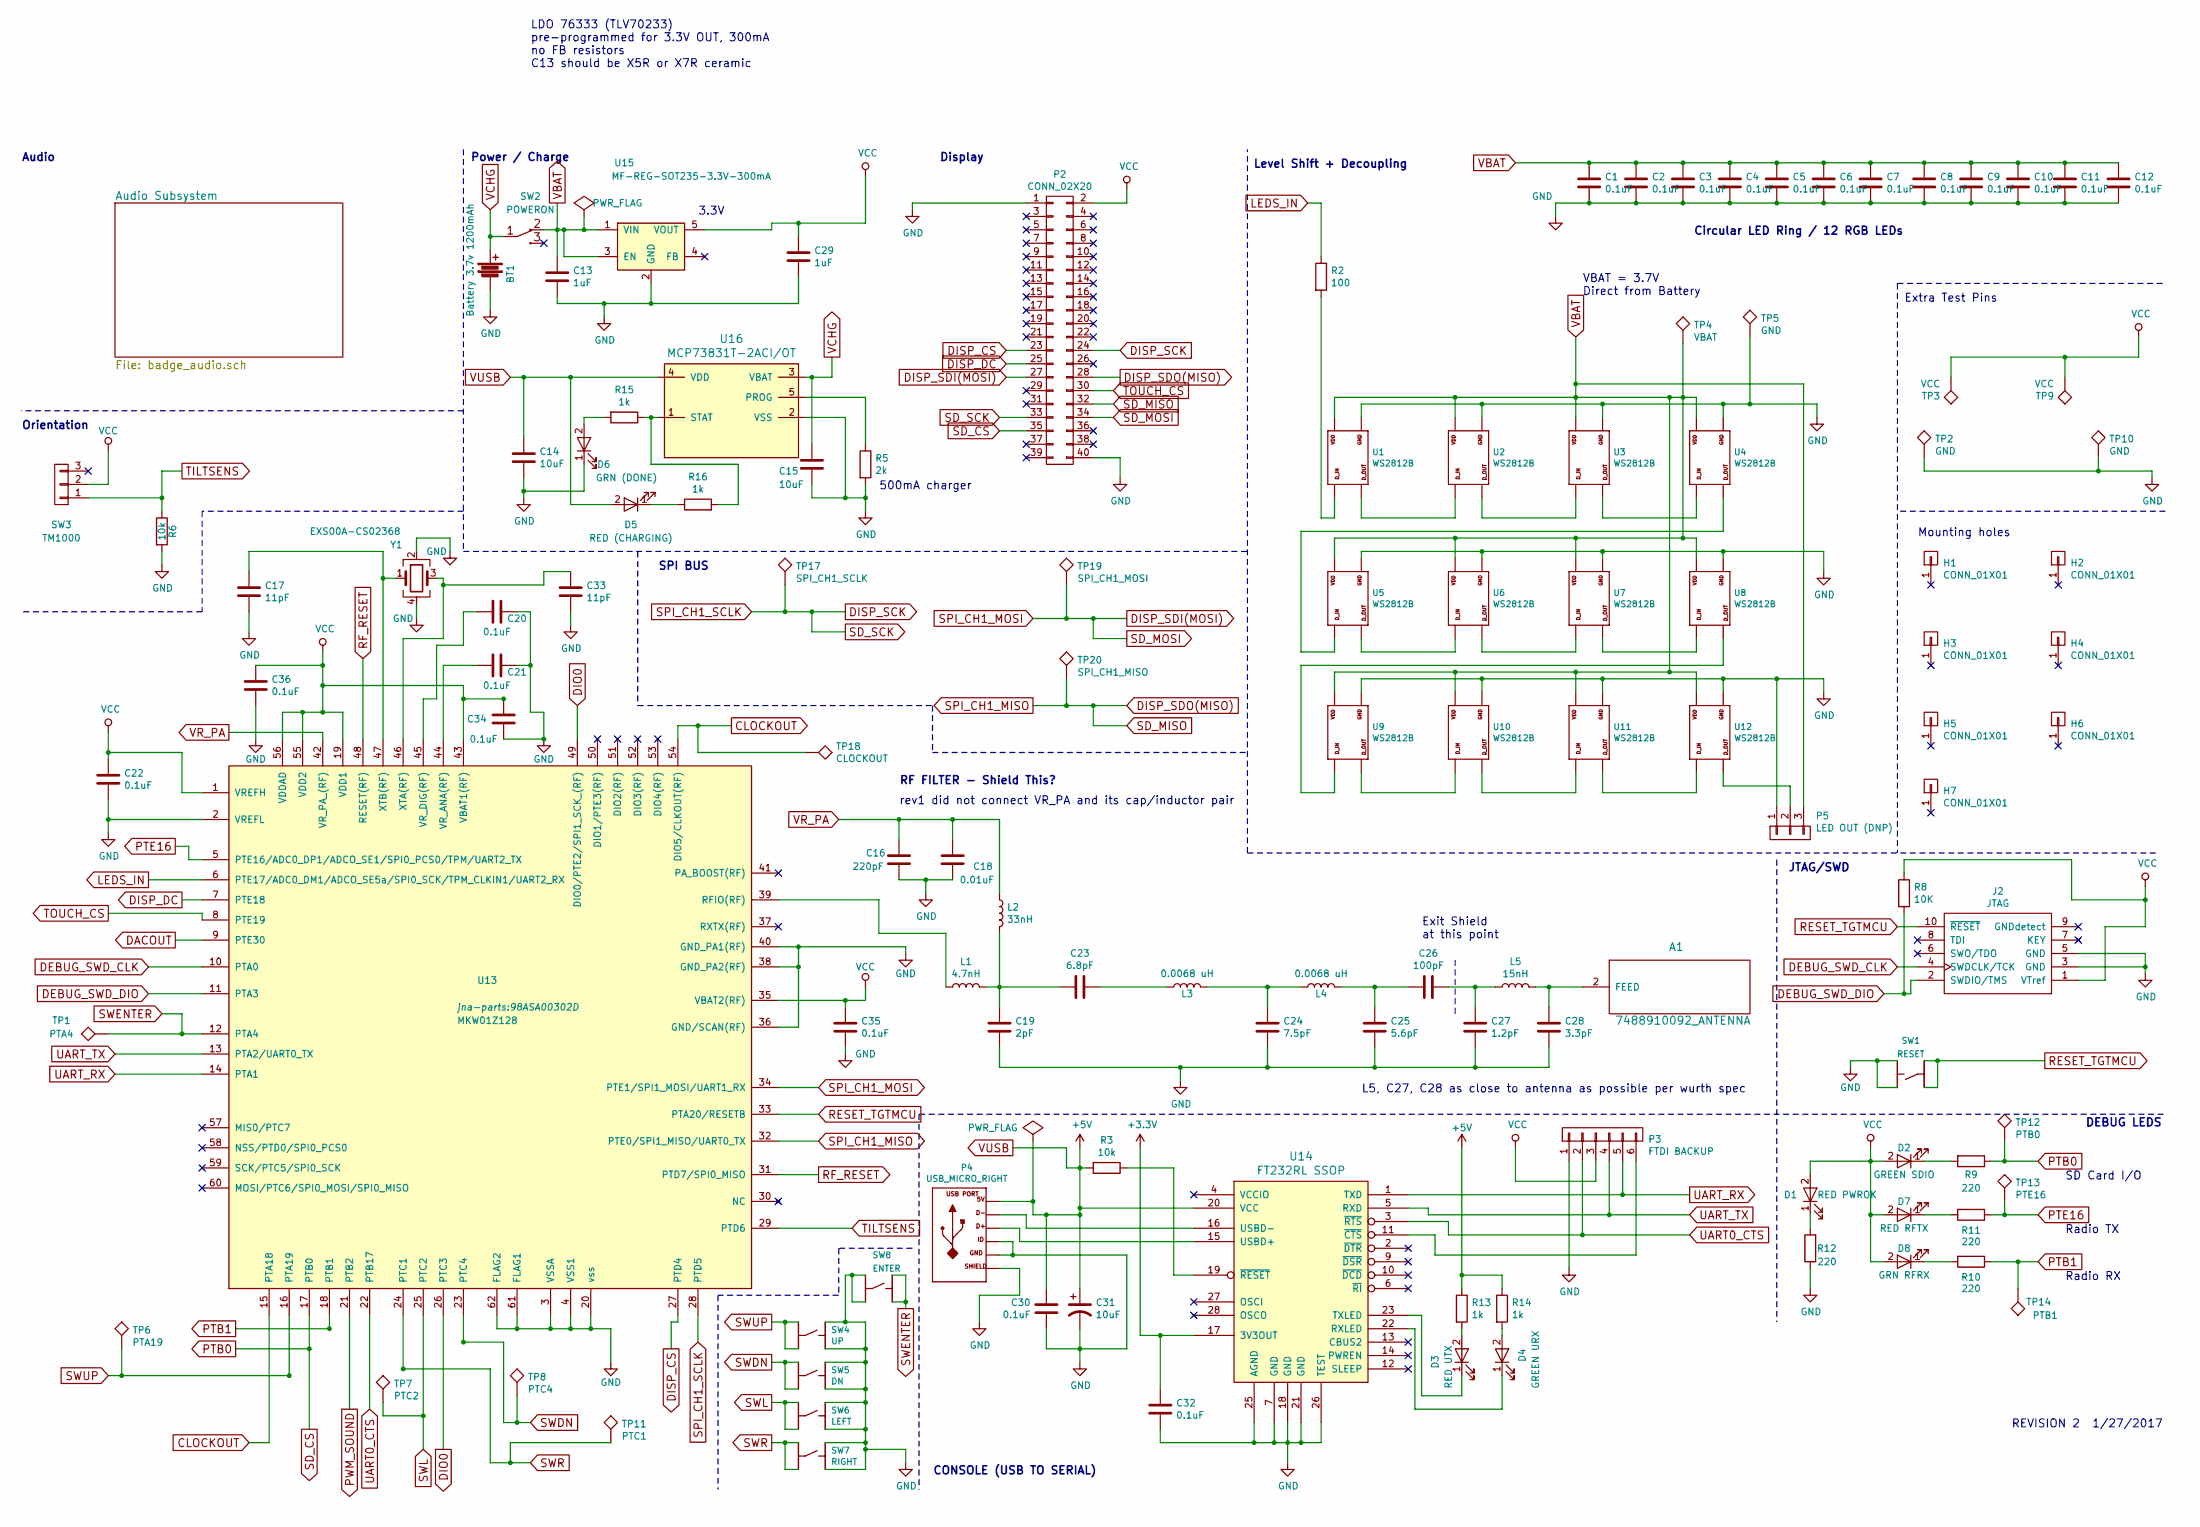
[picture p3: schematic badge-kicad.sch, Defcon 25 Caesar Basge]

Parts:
A1: 7488910092_ANTENNA; Antenna_Wurth_7488910092
BT1: Battery 3.7v 1200mAh; JST_PH_S2B-PH-SM4-TB_02x2.00mm_Angled
C1, C2, C3, C4, C5, C6, C7, C8, C9, C10, C11, C12, C20, C21, C22, C30, C32, C34, C35, C36: 0.1uF; C_0805_HandSoldering
C13, C29: 1uF; C_0805_HandSoldering
C14, C15: 10uF; C_1206
C16: 220pF; C_0805_HandSoldering
C17, C33: 11pF; C_0805_HandSoldering
C18: 0.01uF; C_0603_HandSoldering
C19: 2pF; C_0603_HandSoldering
C23: 6.8pF; C_0603_HandSoldering
C24: 7.5pF; C_0603_HandSoldering
C25: 5.6pF; C_0805_HandSoldering
C26: 100pF; C_0805_HandSoldering
C27: 1.2pF; C_0805_HandSoldering
C28: 3.3pF; C_0805_HandSoldering
C31: 10uF; C_0805_HandSoldering
D1: RED PWROK; LED_0805
D2: GREEN SDIO; LED_0805
D3: RED UTX; LED_0805
D4: GREEN URX; LED_0805
D5: RED (CHARGING); LED_0805
D6: GRN (DONE); LED_0805
D7: RED RFTX; LED_0805
D8: GRN RFRX; LED_0805
H1, H2, H3, H4, H5, H6, H7: CONN_01X01; MountingHole_3.2mm_M3_DIN965
J2: JTAG; Pin_Header_Straight_2x05_Pitch1.27mm
L1: 4.7nH; Neosid_Inductor_SM0603CG
L2: 33nH; Neosid_Inductor_SM0603CG
L3, L4: 0.0068 uH; Neosid_Inductor_SM0603CG
L5: 15nH; Neosid_Inductor_SM0603CG
P2: CONN_02X20; IDC_HEADER_FEMALE
P3: FTDI BACKUP; Pin_Header_Straight_1x06
P4: USB_MICRO_RIGHT; MF_Connectors-MICROUSB-RIGHT
P5: LED OUT (DNP); Pin_Header_Straight_1x03
R2: 100; R_0805
R3, R6: 10k; R_0805
R5: 2k; R_0805
R8: 10K; R_0805
R9, R10, R11, R12: 220; R_0805
R13, R14, R15, R16: 1k; R_0805
SW1: RESET; MF_Switches-TACT4.2MM
SW2: POWERON; SW_SPDT_PCM12
SW3: TM1000
SW4: UP; MF_Switches-TACT4.2MM
SW5: DN; MF_Switches-TACT4.2MM
SW6: LEFT; MF_Switches-TACT4.2MM
SW7: RIGHT; MF_Switches-TACT4.2MM
SW8: ENTER; MF_Switches-TACT4.2MM
TP1: PTA4; Measurement_Point_Round-TH_Small
TP2, TP5, TP10: GND; Measurement_Point_Round-TH_Small
TP3, TP9: VCC; Measurement_Point_Round-TH_Small
TP4: VBAT; Measurement_Point_Round-TH_Small
TP6: PTA19; Measurement_Point_Round-TH_Small
TP7: PTC2; Measurement_Point_Round-TH_Small
TP8: PTC4; Measurement_Point_Round-TH_Small
TP11: PTC1; Measurement_Point_Round-TH_Small
TP12: PTB0; Measurement_Point_Round-TH_Small
TP13: PTE16; Measurement_Point_Round-TH_Small
TP14: PTB1; Measurement_Point_Round-TH_Small
TP17: SPI_CH1_SCLK; Measurement_Point_Round-TH_Small
TP18: CLOCKOUT; Measurement_Point_Round-TH_Small
TP19: SPI_CH1_MOSI; Measurement_Point_Round-TH_Small
TP20: SPI_CH1_MISO; Measurement_Point_Round-TH_Small
U1, U2, U3, U4, U5, U6, U7, U8, U9, U10, U11, U12: WS2812B; MF_LEDs-WS2812B
U13: MKW01Z128; 98ASA00302D
U14: FT232RL SSOP; SSOP-28_5.3x10.2mm_Pitch0.65mm
U15: MF-REG-SOT235-3.3V-300mA; SOT-23-5
U16: MCP73831T-2ACI/OT; SOT-23-5
Y1: EXS00A-CS02368; Crystal_EXS00A-CS02368

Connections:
+3V3: C32.1, U14.17 (3V3OUT)
CLOCKOUT: TP18.1, U13.15 (PTA18), U13.54 (DIO5/CLKOUT(RF))
DACOUT: U13.9 (PTE30); also elsewhere on the board
DEBUG_SWD_CLK: J2.4 (SWDCLK/TCK), U13.10 (PTA0)
DEBUG_SWD_DIO: J2.2 (SWDIO/TMS), R8.2, U13.11 (PTA3)
DIO0: U13.26 (PTC3), U13.49 (DIO0/PTE2/SPI1_SCK_(RF))
DISP_CS: P2.23, U13.27 (PTD4)
DISP_DC: P2.25, U13.7 (PTE18)
DISP_SCK: P2.24, P2.33, TP17.1, U13.28 (PTD5)
DISP_SDI(MOSI): P2.27, P2.34, TP19.1, U13.34 (PTE1/SPI1_MOSI/UART1_RX)
DISP_SDO(MISO): P2.28, P2.32, TP20.1, U13.32 (PTE0/SPI1_MISO/UART0_TX)
GND: BT1.2, C1.2, C2.2, C3.2, C4.2, C5.2, C6.2, C7.2, C8.2, C9.2, C10.2, C11.2, C12.2, C13.2, C14.2, C15.2, C16.2, C17.2, C18.2, C19.2, C20.1, C21.1, C22.2, C24.2, C25.2, C27.2, C28.2, C29.2, C30.2, C31.2, C32.2, C33.2, C34.1, C35.2, C36.2, D6.1 (K), J2.3 (GND), J2.5 (GND), P2.1, P2.40, P3.1, P4.4 (ID), P4.5 (GND), P4.S1 (SLD), P4.S2 (SLD), P4.S3 (SLD), P4.S4 (SLD), P4.S5 (SLD), P4.S6 (SLD), P5.1, R5.2, R6.2, R12.1, SW1.P$1, SW1.P$2, SW4.P$1, SW4.P$2, SW5.P$1, SW5.P$2, SW6.P$1, SW6.P$2, SW7.P$1, SW7.P$2, SW8.P$3, SW8.P$4, TP2.1, TP5.1, TP10.1, U1.P$3 (VSS), U2.P$3 (VSS), U3.P$3 (VSS), U4.P$3 (VSS), U5.P$3 (VSS), U6.P$3 (VSS), U7.P$3 (VSS), U8.P$3 (VSS), U9.P$3 (VSS), U10.P$3 (VSS), U11.P$3 (VSS), U12.P$3 (VSS), U13.2 (VREFL), U13.3 (VSSA), U13.4 (VSS1), U13.20 (vss), U13.36 (GND/SCAN(RF)), U13.38 (GND_PA2(RF)), U13.40 (GND_PA1(RF)), U13.61 (FLAG1), U13.62 (FLAG2), U14.7 (GND), U14.18 (GND), U14.21 (GND), U14.25 (AGND), U14.26 (TEST), U15.2 (GND), U16.2 (VSS), Y1.2, Y1.4; also elsewhere on the board
LEDS_IN: R2.1, U13.6 (PTE17/ADC0_DM1/ADCO_SE5a/SPI0_SCK/TPM_C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)
unnamed: A1.2 (FEED), C28.1, L5.2
unnamed: C17.1, U13.47 (XTB(RF)), Y1.1
unnamed: C19.1, C23.2, L1.2, L2.2
unnamed: C20.2, U13.45 (VR_DIG(RF))
unnamed: C21.2, U13.44 (VR_ANA(RF))
unnamed: C23.1, L3.1
unnamed: C24.1, L3.2, L4.1
unnamed: C25.1, C26.2, L4.2
unnamed: C26.1, C27.1, L5.1
unnamed: C33.1, U13.46 (XTA(RF)), Y1.3
unnamed: D1.1 (K), R12.2
unnamed: D2.1 (K), R9.2
unnamed: D3.1 (K), U14.23 (TXLED)
unnamed: D3.2 (A), R13.2
unnamed: D4.1 (K), U14.22 (RXLED)
unnamed: D4.2 (A), R14.2
unnamed: D5.1 (K), R16.1
unnamed: D6.2 (A), R15.2
unnamed: D7.1 (K), R11.2
unnamed: D8.1 (K), R10.2
unnamed: L1.1, U13.39 (RFIO(RF))
unnamed: P3.6, U14.11 (~CTS)
unnamed: P4.2 (D-), U14.16 (USBD-)
unnamed: P4.3 (D+), U14.15 (USBD+)
unnamed: P5.2, U12.P$2 (DOUT)
unnamed: R2.2, U1.P$4 (DIN)
unnamed: R3.1, U14.19 (~RESET)
unnamed: R5.1, U16.5 (PROG)
unnamed: R15.1, R16.2, U16.1 (STAT)
unnamed: U1.P$2 (DOUT), U2.P$4 (DIN)
unnamed: U2.P$2 (DOUT), U3.P$4 (DIN)
unnamed: U3.P$2 (DOUT), U4.P$4 (DIN)
unnamed: U4.P$2 (DOUT), U5.P$4 (DIN)
unnamed: U5.P$2 (DOUT), U6.P$4 (DIN)
unnamed: U6.P$2 (DOUT), U7.P$4 (DIN)
unnamed: U7.P$2 (DOUT), U8.P$4 (DIN)
unnamed: U8.P$2 (DOUT), U9.P$4 (DIN)
unnamed: U10.P$2 (DOUT), U11.P$4 (DIN)
unnamed: U9.P$2 (DOUT), U10.P$4 (DIN)
unnamed: U11.P$2 (DOUT), U12.P$4 (DIN)
PTB0: P2.35, R9.1, TP12.1, U13.17 (PTB0)
PTB1: R10.1, TP14.1, U13.18 (PTB1)
PTE16: R11.1, TP13.1, U13.5 (PTE16/ADC0_DP1/ADCO_SE1/SPI0_PCS0/TPM/U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)
PWM_SOUND: U13.21 (PTB2); also elsewhere on the board
RESET_TGTMCU: J2.10 (~RESET), SW1.P$3, SW1.P$4, U13.33 (PTA20/RESETB)
RF_RESET: U13.31 (PTD7/SPI0_MISO), U13.48 (RESET(RF))
SWDN: SW5.P$3, SW5.P$4, TP8.1, U13.23 (PTC4)
SWENTER: SW8.P$1, SW8.P$2, TP1.1, U13.12 (PTA4)
SWL: SW6.P$3, SW6.P$4, TP7.1, U13.25 (PTC2)
SWR: SW7.P$3, SW7.P$4, TP11.1, U13.24 (PTC1)
SWUP: SW4.P$3, SW4.P$4, TP6.1, U13.16 (PTA19)
TILTSENS: R6.1, SW3.1, U13.29 (PTD6)
TOUCH_CS: P2.30, U13.8 (PTE19)
UART0_CTS: P3.2, U13.22 (PTB17), U14.3 (~RTS)
UART_RX: P3.5, U13.14 (PTA1), U14.1 (TXD)
UART_TX: P3.4, U13.13 (PTA2/UART0_TX), U14.5 (RXD)
VBAT: C1.1, C2.1, C3.1, C4.1, C5.1, C6.1, C7.1, C8.1, C9.1, C10.1, C11.1, C12.1, C13.1, P5.3, SW2.2 (NC), TP4.1, U1.P$1 (VDD), U2.P$1 (VDD), U3.P$1 (VDD), U4.P$1 (VDD), U5.P$1 (VDD), U6.P$1 (VDD), U7.P$1 (VDD), U8.P$1 (VDD), U9.P$1 (VDD), U10.P$1 (VDD), U11.P$1 (VDD), U12.P$1 (VDD), U15.1 (VIN), U15.3 (EN); also elsewhere on the board
VCC: C22.1, C29.1, C34.2, C35.1, C36.1, D1.2 (A), D2.2 (A), D7.2 (A), D8.2 (A), J2.1 (VTref), P2.2, P3.3, R8.1, SW3.2, TP3.1, TP9.1, U13.1 (VREFH), U13.19 (VDD1), U13.35 (VBAT2(RF)), U13.43 (VBAT1(RF)), U13.55 (VDD2), U13.56 (VDDAD), U15.5 (VOUT)
VCHG: BT1.1, C15.1, SW2.1 (COM), U16.3 (VBAT)
VR_PA: C16.1, C18.1, L2.1, U13.42 (VR_PA_(RF))
VUSB: C14.1, C30.1, C31.1, D5.2 (A), P4.1 (5V), R3.2, R13.1, R14.1, U14.20 (VCC), U16.4 (VDD)

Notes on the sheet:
Level Shift + Decoupling
Circular LED Ring / 12 RGB LEDs
JTAG/SWD
Display
Audio
Power / Charge
RF FILTER - Shield This?
SPI BUS
Orientation
CONSOLE (USB TO SERIAL)
DEBUG LEDS
LDO 76333 (TLV70233) pre-programmed for 3.3V OUT, 300mA no FB resistors C13 should be X5R or X7R ceramic
500mA charger
3.3V
VBAT = 3.7V Direct from Battery
Radio RX
Radio TX
SD Card I/O
rev1 did not connect VR_PA and its cap/inductor pair
L5, C27, C28 as close to antenna as possible per wurth spec
Exit Shield at this point
Mounting holes
Extra Test Pins
REVISION 2 1/27/2017

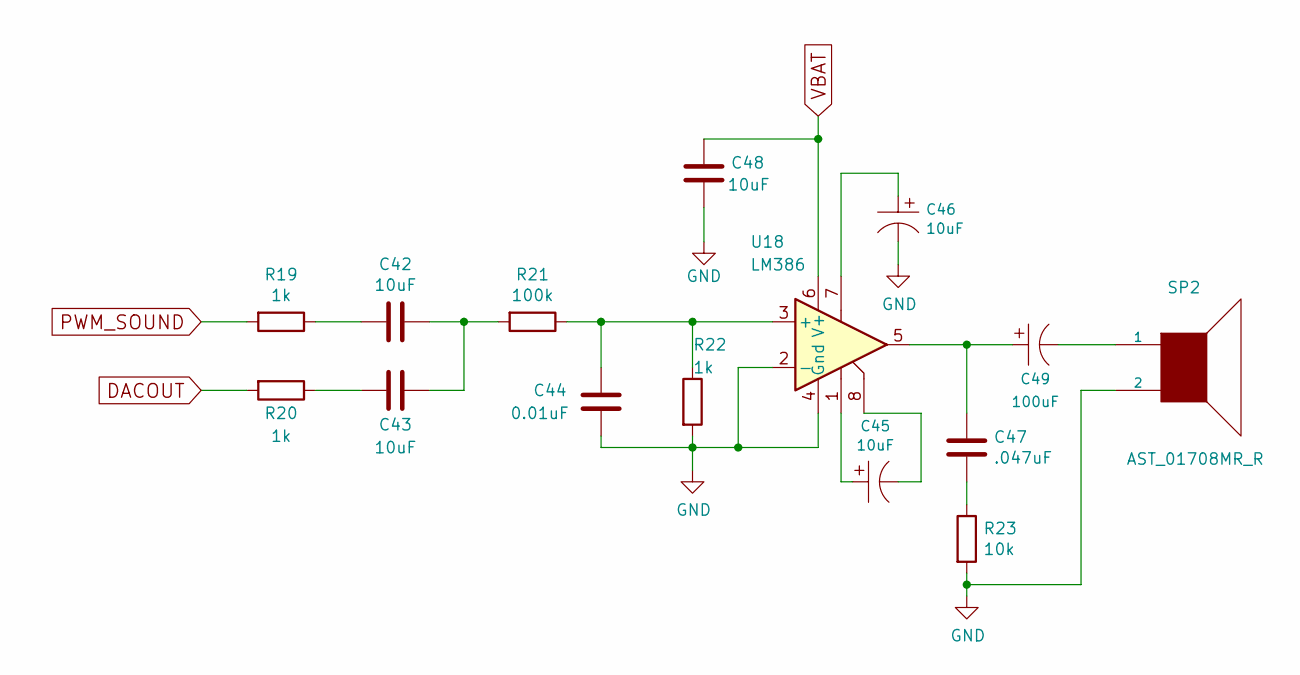
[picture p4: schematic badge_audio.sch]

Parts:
C42, C43, C48: 10uF; C_0805_HandSoldering
C44: 0.01uF; C_0603_HandSoldering
C45, C46: 10uF; MF_Passives-CP4MM
C47: .047uF; C_0805_HandSoldering
C49: 100uF; MF_Passives-CP6.3MM
R19, R20, R22: 1k; R_0805
R21: 100k; R_0805
R23: 10k; R_0805
SP2: AST_01708MR_R; SPEAKER_AST_01708MR_R
U18: LM386; SOIC-8-N

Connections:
DACOUT: R20.2; also elsewhere on the board
GND: C44.2, C46.P$2, C48.2, R22.2, R23.2, SP2.2, U18.2 (-), U18.4 (Gnd); also elsewhere on the board
unnamed: C42.1, C43.1, R21.2
unnamed: C42.2, R19.1
unnamed: C43.2, R20.1
unnamed: C44.1, R21.1, R22.1, U18.3 (+)
unnamed: C45.P$1, U18.1
unnamed: C45.P$2, U18.8
unnamed: C46.P$1, U18.7
unnamed: C47.1, C49.P$1, U18.5
unnamed: C47.2, R23.1
unnamed: C49.P$2, SP2.1
PWM_SOUND: R19.2; also elsewhere on the board
VBAT: C48.1, U18.6 (V+); also elsewhere on the board

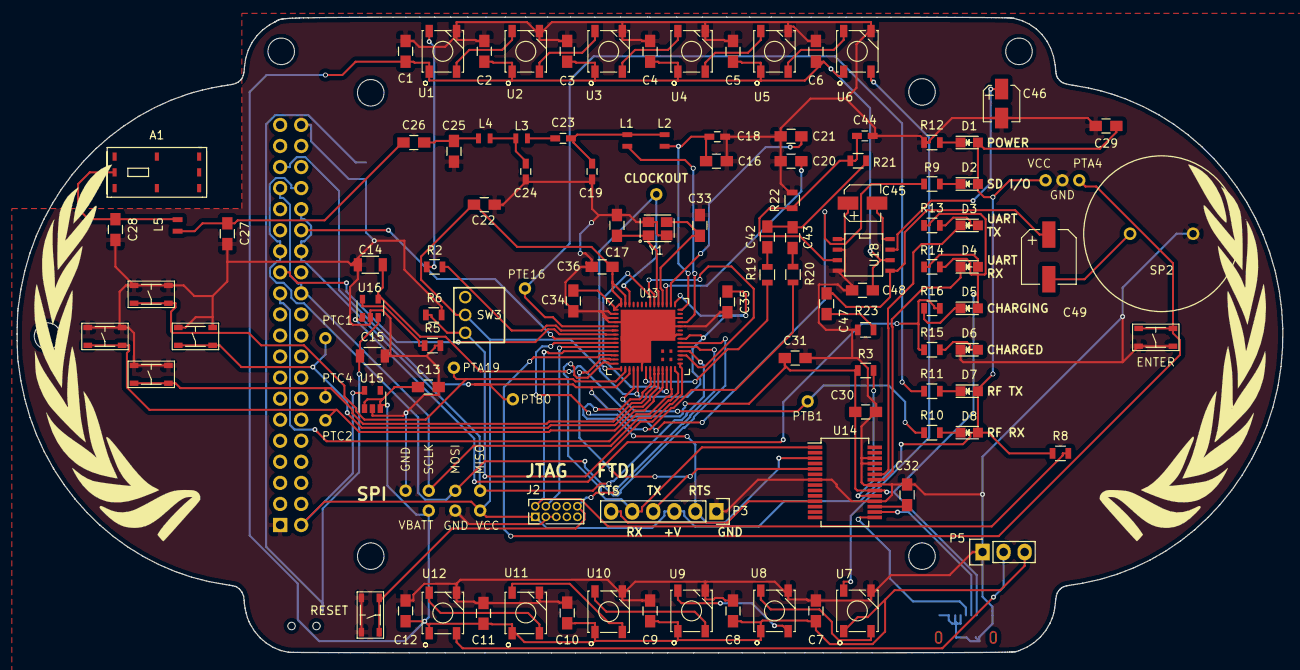
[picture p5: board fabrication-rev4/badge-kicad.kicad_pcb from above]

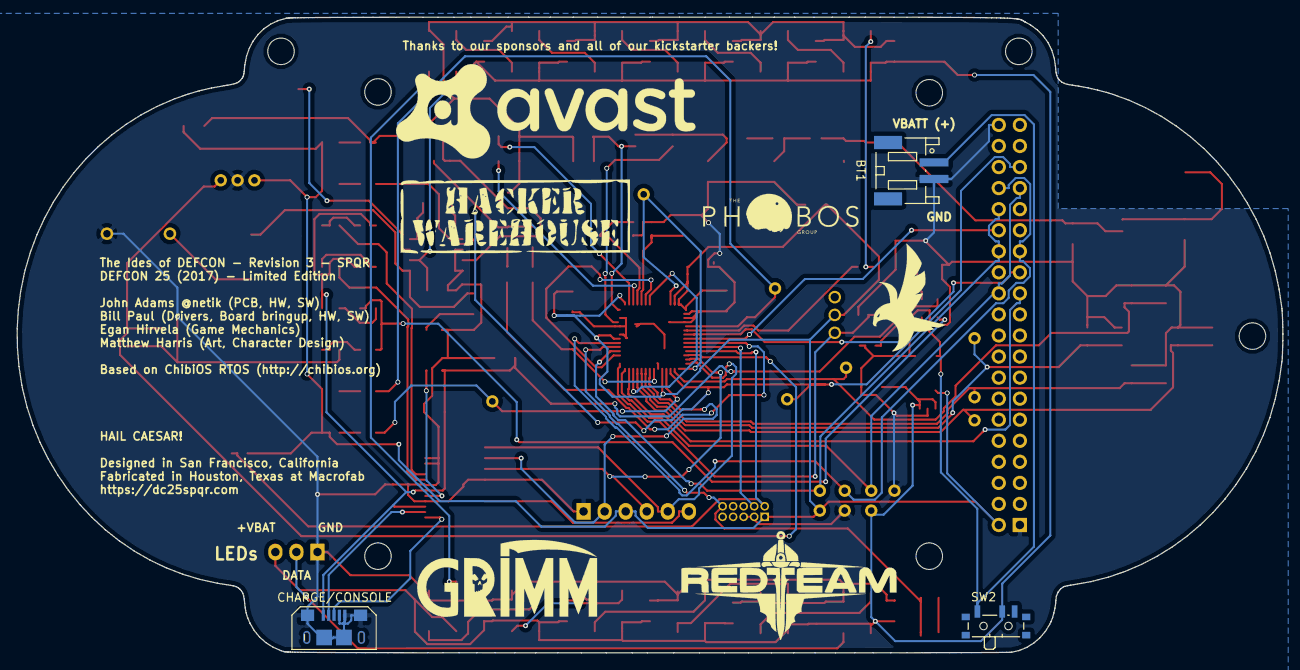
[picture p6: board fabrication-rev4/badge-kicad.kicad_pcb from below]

Board: 2 copper layers, 152.7 x 76.7 mm, 134 parts (3 on the bottom side), 84 nets.

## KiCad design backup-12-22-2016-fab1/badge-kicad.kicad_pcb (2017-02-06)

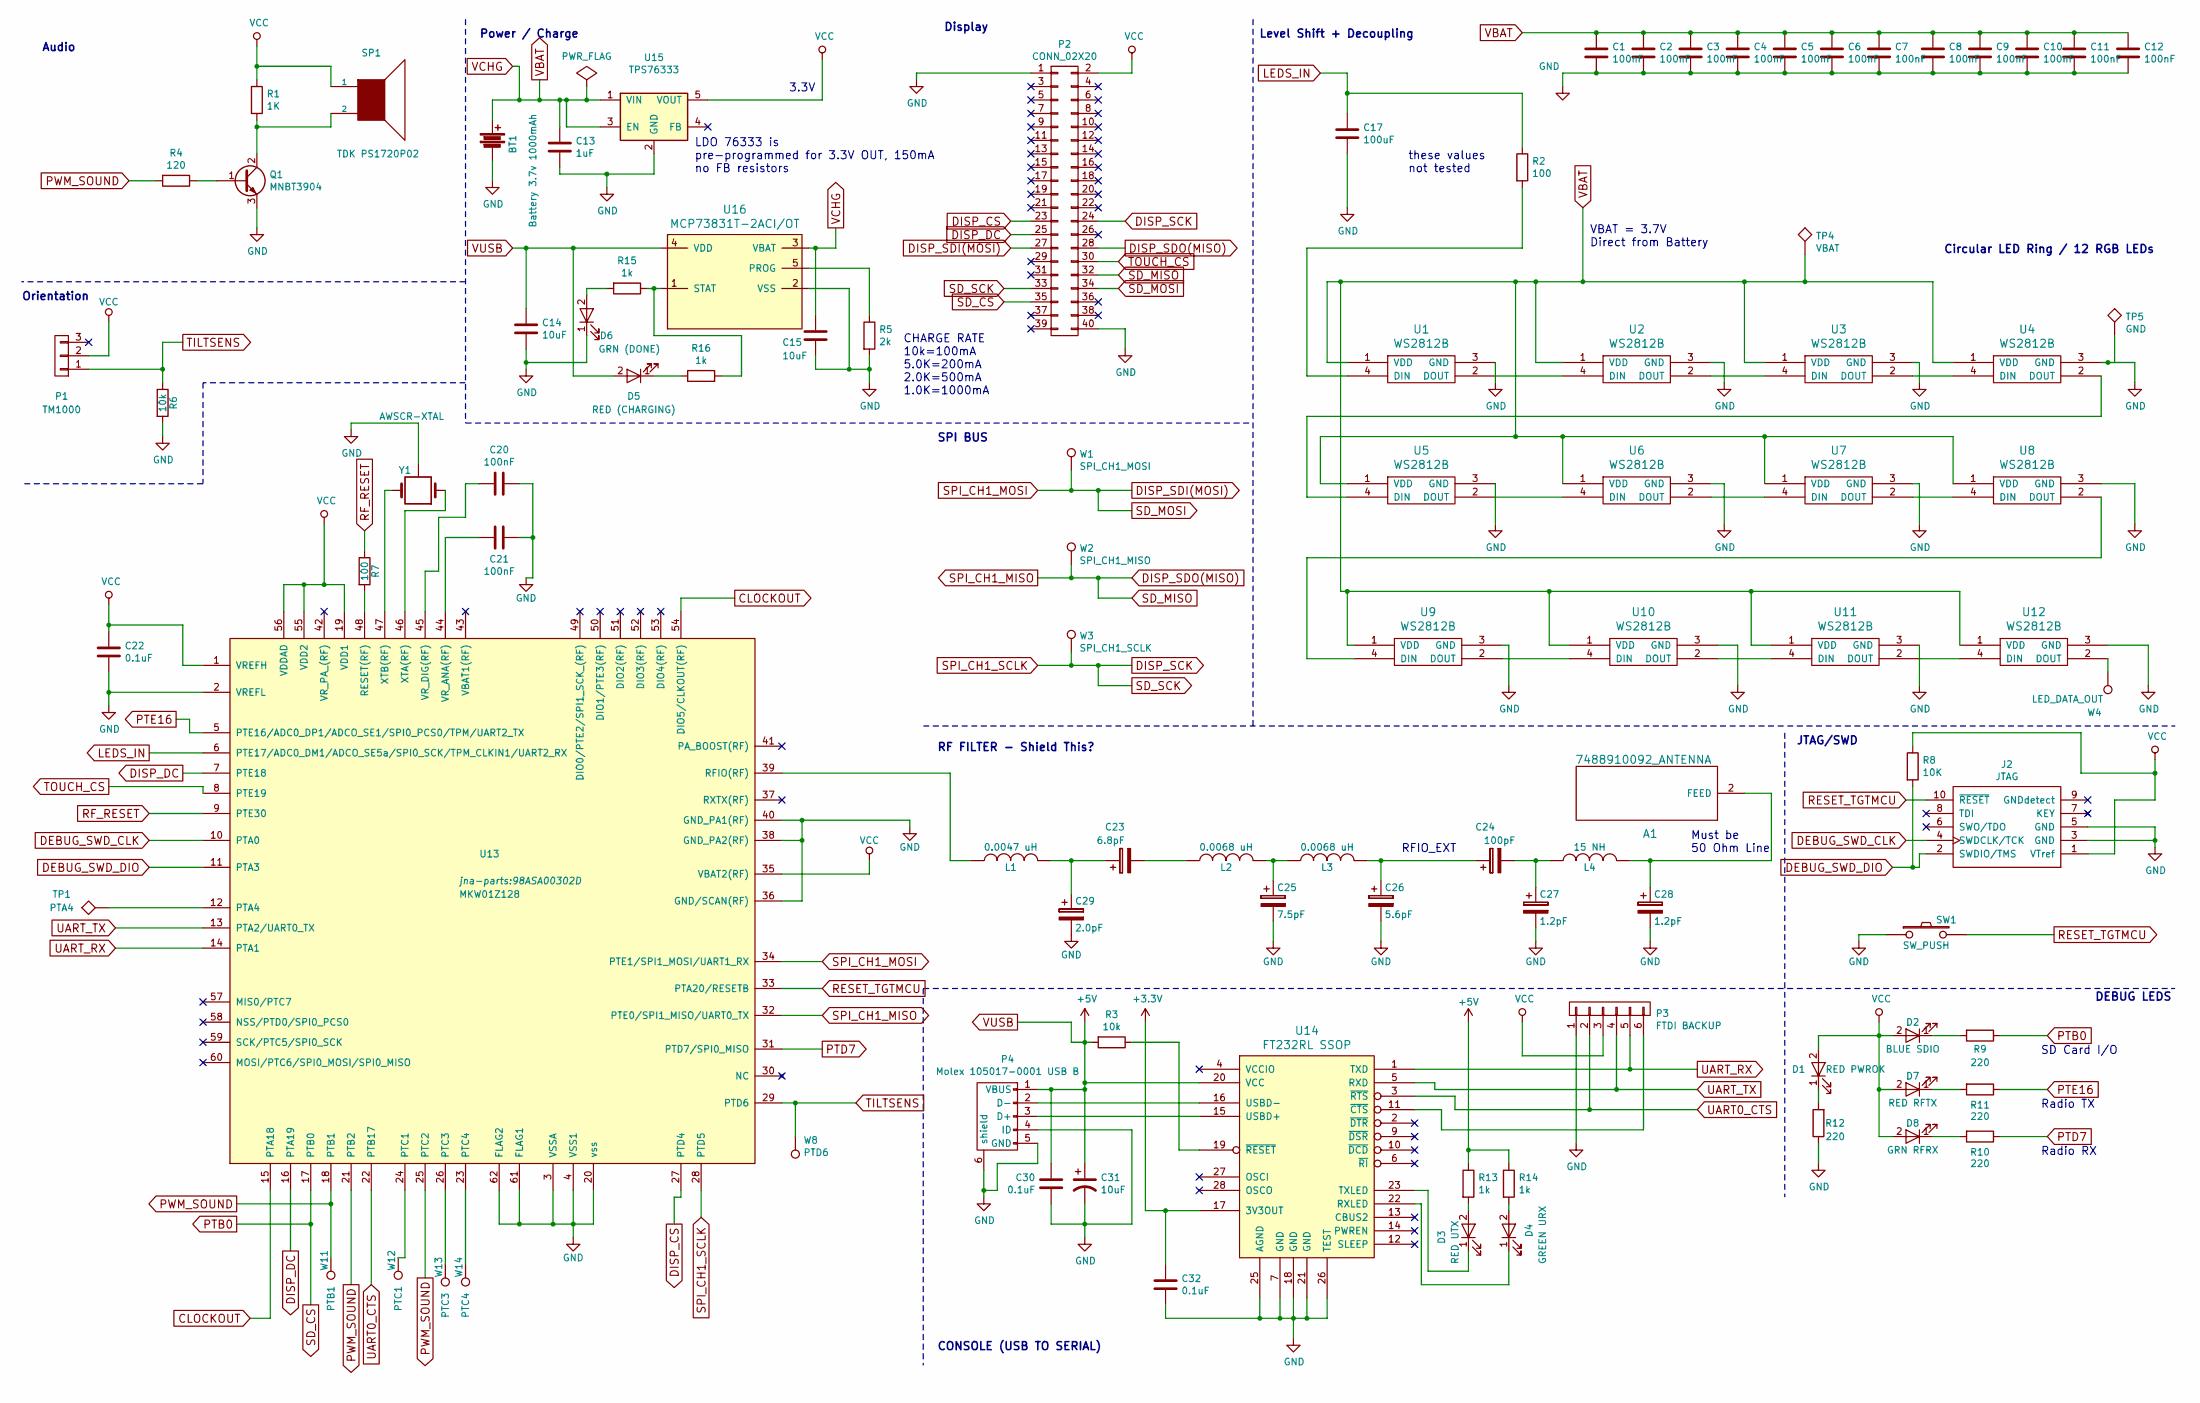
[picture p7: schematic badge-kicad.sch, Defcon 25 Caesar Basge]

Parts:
A1: 7488910092_ANTENNA; Antenna_Wurth_7488910092
BT1: Battery 3.7v 1000mAh; JST_PH_S2B-PH-SM4-TB_02x2.00mm_Angled
C1, C2, C3, C4, C5, C6, C7, C8, C9, C10, C11, C12, C20, C21: 100nF; C_0805_HandSoldering
C13: 1uF; C_0805_HandSoldering
C14, C15, C31: 10uF; C_0805_HandSoldering
C17: 100uF; C_0805_HandSoldering
C22, C30, C32: 0.1uF; C_0805_HandSoldering
C23: 6.8pF; C_0805_HandSoldering
C24: 100pF; C_0805_HandSoldering
C25: 7.5pF; C_0805_HandSoldering
C26: 5.6pF; C_0805_HandSoldering
C27, C28: 1.2pF; C_0805_HandSoldering
C29: 2.0pF; C_0805_HandSoldering
D1: RED PWROK; LED_0805
D2: BLUE SDIO; LED_0805
D3: RED UTX; LED_0805
D4: GREEN URX; LED_0805
D5: RED (CHARGING); LED_0805
D6: GRN (DONE); LED_0805
D7: RED RFTX; LED_0805
D8: GRN RFRX; LED_0805
J2: JTAG; Pin_Header_Straight_2x05_Pitch1.27mm
L1: 0.0047 uH; Neosid_Inductor_SM1206
L2, L3: 0.0068 uH; Neosid_Inductor_SM1206
L4: 15 NH; Neosid_Inductor_SM1206
P1: TM1000
P2: CONN_02X20; IDC_HEADER_FEMALE
P3: FTDI BACKUP; Pin_Header_Straight_1x06
P4: Molex 105017-0001 USB B; USB_Micro-B
Q1: MNBT3904; SOT-23
R1: 1K; R_0805
R2, R7: 100; R_0805
R3, R6: 10k; R_0805
R4: 120; R_0805
R5: 2k; R_0805
R8: 10K; R_0805
R9, R10, R11, R12: 220; R_0805
R13, R14, R15, R16: 1k; R_0805
SP1: TDK PS1720P02; TDK_PS1720PD2
SW1: SW_PUSH; SW_SPST_B3S-1000
TP1: PTA4; Measurement_Point_Square-TH_Small
TP4: VBAT; Measurement_Point_Square-TH_Small
TP5: GND; Measurement_Point_Square-TH_Small
U1, U2, U3, U4, U5, U6, U7, U8, U9, U10, U11, U12: WS2812B; LED_WS2812B-PLCC4
U13: MKW01Z128; 98ASA00302D
U14: FT232RL SSOP; SSOP-28_5.3x10.2mm_Pitch0.65mm
U15: TPS76333; SOT-23-5
U16: MCP73831T-2ACI/OT; SOT-23-5
W1: SPI_CH1_MOSI; Measurement_Point_Round-TH_Small
W2: SPI_CH1_MISO; Measurement_Point_Round-TH_Small
W3: SPI_CH1_SCLK; Measurement_Point_Round-TH_Small
W4: LED_DATA_OUT; Measurement_Point_Round-TH_Small
W8: PTD6; Measurement_Point_Round-TH_Small
W11: PTB1; Measurement_Point_Round-TH_Small
W12: PTC1; Measurement_Point_Round-TH_Small
W13: PTC3; Measurement_Point_Round-TH_Small
W14: PTC4; Measurement_Point_Round-TH_Small
Y1: AWSCR-XTAL; AWSCR_XTAL

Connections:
+3V3: C32.1, U14.17 (3V3OUT)
CLOCKOUT: U13.15 (PTA18), U13.54 (DIO5/CLKOUT(RF))
DEBUG_SWD_CLK: J2.4 (SWDCLK/TCK), U13.10 (PTA0)
DEBUG_SWD_DIO: J2.2 (SWDIO/TMS), R8.2, U13.11 (PTA3)
DISP_CS: P2.23, U13.27 (PTD4)
DISP_DC: P2.25, U13.7 (PTE18), U13.16 (PTA19)
DISP_SCK: P2.24, P2.33, U13.28 (PTD5), W3.1
DISP_SDI(MOSI): P2.27, P2.34, U13.34 (PTE1/SPI1_MOSI/UART1_RX), W1.1
DISP_SDO(MISO): P2.28, P2.32, U13.32 (PTE0/SPI1_MISO/UART0_TX), W2.1
GND: BT1.2, C1.2, C2.2, C3.2, C4.2, C5.2, C6.2, C7.2, C8.2, C9.2, C10.2, C11.2, C12.2, C13.2, C14.2, C15.2, C17.2, C20.1, C21.1, C22.2, C25.2, C26.2, C27.2, C28.2, C29.2, C30.2, C31.2, C32.2, D6.1 (K), J2.3 (GND), J2.5 (GND), P2.1, P2.40, P3.1, P4.4 (ID), P4.5 (GND), P4.6 (shield), Q1.3 (E), R5.2, R6.2, R12.1, SW1.1, TP5.1, U1.3 (GND), U2.3 (GND), U3.3 (GND), U4.3 (GND), U5.3 (GND), U6.3 (GND), U7.3 (GND), U8.3 (GND), U9.3 (GND), U10.3 (GND), U11.3 (GND), U12.3 (GND), U13.2 (VREFL), U13.3 (VSSA), U13.4 (VSS1), U13.20 (vss), U13.36 (GND/SCAN(RF)), U13.38 (GND_PA2(RF)), U13.40 (GND_PA1(RF)), U13.61 (FLAG1), U13.62 (FLAG2), U14.7 (GND), U14.18 (GND), U14.21 (GND), U14.25 (AGND), U14.26 (TEST), U15.2 (GND), U16.2 (VSS), Y1.3 (GND); also elsewhere on the board
LEDS_IN: C17.1, R2.1, U13.6 (PTE17/ADC0_DM1/ADCO_SE5a/SPI0_SCK/TPM_C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)
unnamed: A1.2 (FEED), C28.1, L4.2
unnamed: C20.2, U13.45 (VR_DIG(RF))
unnamed: C21.2, U13.44 (VR_ANA(RF))
unnamed: C23.1, C29.1, L1.2
unnamed: C23.2, L2.1
unnamed: C24.1, C26.1, L3.2
unnamed: C24.2, C27.1, L4.1
unnamed: C25.1, L2.2, L3.1
unnamed: D1.1 (K), R12.2
unnamed: D2.1 (K), R9.2
unnamed: D3.1 (K), U14.23 (TXLED)
unnamed: D3.2 (A), R13.2
unnamed: D4.1 (K), U14.22 (RXLED)
unnamed: D4.2 (A), R14.2
unnamed: D5.1 (K), R16.1
unnamed: D6.2 (A), R15.2
unnamed: D7.1 (K), R11.2
unnamed: D8.1 (K), R10.2
unnamed: L1.1, U13.39 (RFIO(RF))
unnamed: P3.6, U14.11 (~CTS)
unnamed: P4.2 (D-), U14.16 (USBD-)
unnamed: P4.3 (D+), U14.15 (USBD+)
unnamed: Q1.1 (B), R4.1
unnamed: Q1.2 (C), R1.2, SP1.2
unnamed: R2.2, U1.4 (DIN)
unnamed: R3.1, U14.19 (~RESET)
unnamed: R5.1, U16.5 (PROG)
unnamed: R7.2, U13.48 (RESET(RF))
unnamed: R15.1, R16.2, U16.1 (STAT)
unnamed: TP1.1, U13.12 (PTA4)
unnamed: U1.2 (DOUT), U2.4 (DIN)
unnamed: U2.2 (DOUT), U3.4 (DIN)
unnamed: U3.2 (DOUT), U4.4 (DIN)
unnamed: U4.2 (DOUT), U5.4 (DIN)
unnamed: U5.2 (DOUT), U6.4 (DIN)
unnamed: U6.2 (DOUT), U7.4 (DIN)
unnamed: U7.2 (DOUT), U8.4 (DIN)
unnamed: U8.2 (DOUT), U9.4 (DIN)
unnamed: U10.2 (DOUT), U11.4 (DIN)
unnamed: U9.2 (DOUT), U10.4 (DIN)
unnamed: U11.2 (DOUT), U12.4 (DIN)
unnamed: U12.2 (DOUT), W4.1
unnamed: U13.23 (PTC4), W14.1
unnamed: U13.24 (PTC1), W12.1
unnamed: U13.26 (PTC3), W13.1
unnamed: U13.46 (XTA(RF)), Y1.1
unnamed: U13.47 (XTB(RF)), Y1.2
PTB0: P2.35, R9.1, U13.17 (PTB0)
PTD7: R10.1, U13.31 (PTD7/SPI0_MISO)
PTE16: R11.1, U13.5 (PTE16/ADC0_DP1/ADCO_SE1/SPI0_PCS0/TPM/U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)
PWM_SOUND: R4.2, U13.18 (PTB1), U13.21 (PTB2), U13.25 (PTC2), W11.1
RESET_TGTMCU: J2.10 (~RESET), SW1.2, U13.33 (PTA20/RESETB)
RF_RESET: R7.1, U13.9 (PTE30)
TILTSENS: P1.1, R6.1, U13.29 (PTD6), W8.1
TOUCH_CS: P2.30, U13.8 (PTE19)
UART0_CTS: P3.2, U13.22 (PTB17), U14.3 (~RTS)
UART_RX: P3.5, U13.14 (PTA1), U14.1 (TXD)
UART_TX: P3.4, U13.13 (PTA2/UART0_TX), U14.5 (RXD)
VBAT: BT1.1, C1.1, C2.1, C3.1, C4.1, C5.1, C6.1, C7.1, C8.1, C9.1, C10.1, C11.1, C12.1, C13.1, C15.1, TP4.1, U1.1 (VDD), U2.1 (VDD), U3.1 (VDD), U4.1 (VDD), U5.1 (VDD), U6.1 (VDD), U7.1 (VDD), U8.1 (VDD), U9.1 (VDD), U10.1 (VDD), U11.1 (VDD), U12.1 (VDD), U15.1 (VIN), U15.3 (EN), U16.3 (VBAT); also elsewhere on the board
VCC: C22.1, D1.2 (A), D2.2 (A), D7.2 (A), D8.2 (A), J2.1 (VTref), P1.2, P2.2, P3.3, R1.1, R8.1, SP1.1, U13.1 (VREFH), U13.19 (VDD1), U13.35 (VBAT2(RF)), U13.55 (VDD2), U13.56 (VDDAD), U15.5 (VOUT)
VUSB: C14.1, C30.1, C31.1, D5.2 (A), P4.1 (VBUS), R3.2, R13.1, R14.1, U14.20 (VCC), U16.4 (VDD)

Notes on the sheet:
Level Shift + Decoupling
Circular LED Ring / 12 RGB LEDs
JTAG/SWD
Display
Audio
Power / Charge
RFIO_EXT
RF FILTER - Shield This?
SPI BUS
Orientation
CONSOLE (USB TO SERIAL)
DEBUG LEDS
LDO 76333 is pre-programmed for 3.3V OUT, 150mA no FB resistors
CHARGE RATE 10k=100mA 5.0K=200mA 2.0K=500mA 1.0K=1000mA
3.3V
VBAT = 3.7V Direct from Battery
these values not tested
Must be 50 Ohm Line
Radio RX
Radio TX
SD Card I/O

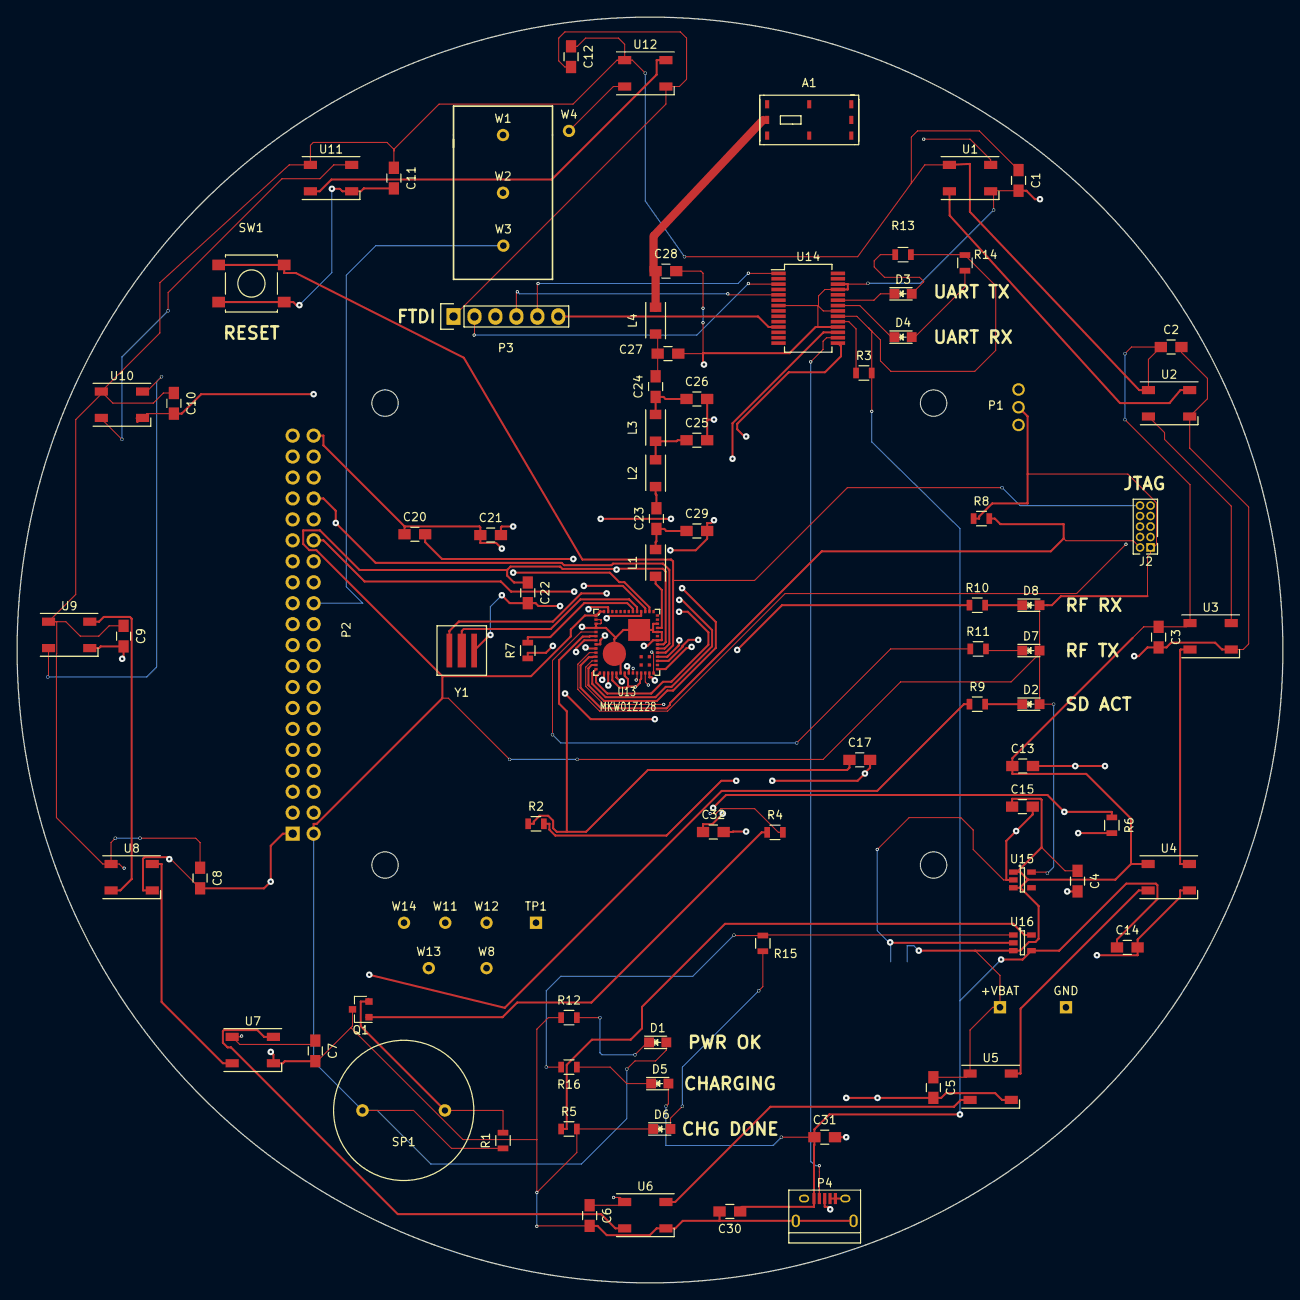
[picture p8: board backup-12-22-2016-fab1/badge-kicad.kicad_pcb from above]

Board: 4 copper layers, 153.5 x 153.5 mm, 96 parts (1 on the bottom side), 72 nets.

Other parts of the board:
+VBAT: VBAT; Measurement_Point_Square-TH_Small
GND: GND; Measurement_Point_Square-TH_Small

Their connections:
GND: GND.1; also elsewhere on the board
VBAT: +VBAT.1; also elsewhere on the board

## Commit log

2016-12-22 remove backups now that we use git, add bom scrape tools
    [bom.csv]
2016-12-23 replace parts with MF parts to save money, add power switch
    [badge-kicad.sch]
2016-12-28 rebuild RF section to match KW01 dev board
    [badge-kicad.sch]
2017-01-17 add backup of files as sent to macrofab for rev1
    [badge-kicad-B.Cu.gbl, badge-kicad-B.Mask.gbs, badge-kicad-B.Paste.gbp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]
2017-01-17 rename backup folders
    [badge-kicad.dsn, badge-kicad.kicad_pcb, badge-kicad.sch]
2017-01-17 checkpoint v2 board
    [badge-kicad-B.Cu.gbl, badge-kicad-B.Mask.gbs, badge-kicad-B.Paste.gbp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]
2017-01-17 checkpoint v2 board backup files
2017-02-06 new board shape, now with DAC, audio amp, and joypad
    [badge-kicad.dsn, badge-kicad.kicad_pcb, badge-kicad.sch]
2017-02-07 add silkscreens and fix some traces
    [badge-kicad.kicad_pcb]
2017-02-07 add badge audio
    [badge_audio.sch]
2017-02-07 Fix the reset button which was tied to ground by mistake
    [badge-kicad.kicad_pcb, badge-kicad.sch]
2017-02-07 swap PTD7 and PTB1
    [badge-kicad.dsn, badge-kicad.kicad_pcb, badge-kicad.sch]
2017-02-07 add text and logos to pcb
    [badge-kicad.kicad_pcb]
2017-02-07 Final rev2, clean up rev1
    [badge-kicad-B.Cu.gbl, badge-kicad-B.Mask.gbs, badge-kicad-B.Paste.gbp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]
2017-02-08 add laurel designs back, switch some caps to 0603 based on BOM
    [badge-kicad.kicad_pcb]
2017-02-08 Revision 2 final layout.
    Add connection for missing VBAT connector, add some decoupling caps on KW01
    Output drill files again.
    [badge-kicad-B.Cu.gbl, badge-kicad-B.Mask.gbs, badge-kicad-B.Paste.gbp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]
2017-02-08 fix typo
    [badge-kicad.sch]
2017-02-08 redo the drill files, send it to macrofab!
    [badge-kicad-Edge.Cuts.gm1]
2017-02-09 update xyrs bom, fix typo
    [badge-kicad.kicad_pcb]
2017-02-09 Move the P4-Net trace far, far away from H4. Potential issue if we resize the hole
    [badge-kicad.kicad_pcb]
2017-03-24 update for fabrication rev3
    [badge-kicad-B.Cu.gbl, badge-kicad-B.Mask.gbs, badge-kicad-B.Paste.gbp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]
2017-04-19 check in changes before modifiying footprint for rev4
    [badge-kicad-B.Cu.gbl, badge-kicad-B.Mask.gbs, badge-kicad-B.Paste.gbp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]
2017-04-20 update footprints, check in everything before rev4
2017-05-04 update for rev4
    [badge-kicad.kicad_pcb]
2017-05-04 add rev4
    [badge-kicad-B.Cu.gbl, badge-kicad-B.Mask.gbs, badge-kicad-B.Paste.gbp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]
2017-05-23 final commit for production
    [badge-kicad-B.Cu.gbl, badge-kicad-B.Mask.gbs, badge-kicad-B.Paste.gbp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]
2017-06-15 push last changes
    [badge-bom.tsv, badge-kicad.kicad_pcb]
2017-06-15 Create README.md
    Update readme with standoffs, screens, and other non-BOM parts
2017-07-10 Make some minot tweaks to work with release versions of KiCad
    John used a nightly build of KiCad to generate the PCB for this project.
    The nightly builds have some features not found in the release versions,
    including some changes to the PCB file format. The main difference is the
    use of the diff_pair_gap and diff_pair_width keywords, which released
    versions of KiCad do not understand.
    Fortunately, becuase all KiCad files are text, we can work around this by
    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
